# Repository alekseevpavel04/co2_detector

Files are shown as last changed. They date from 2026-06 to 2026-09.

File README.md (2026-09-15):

# co2_detector

A battery-powered indoor air-quality monitor built from off-the-shelf parts. It measures CO2, temperature and relative humidity, keeps a history on flash and draws the current CO2 level and graphs on an e-Paper screen. Hardware and firmware are assembled and working; screen design is still being refined (see [STATUS.md](STATUS.md)).

<p>
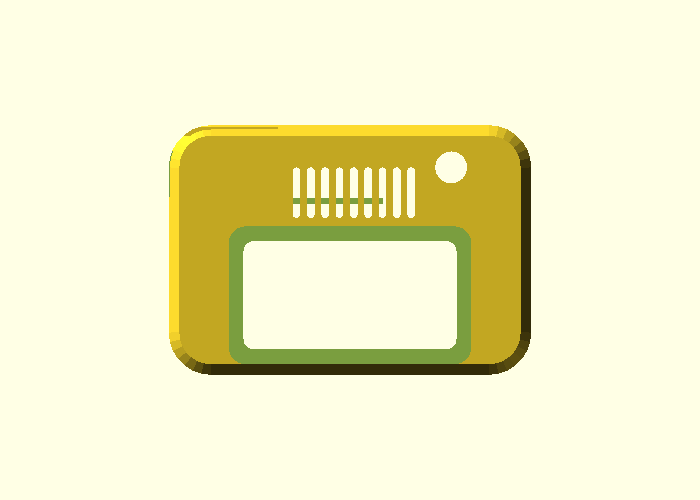
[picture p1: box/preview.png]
Case, front view
  
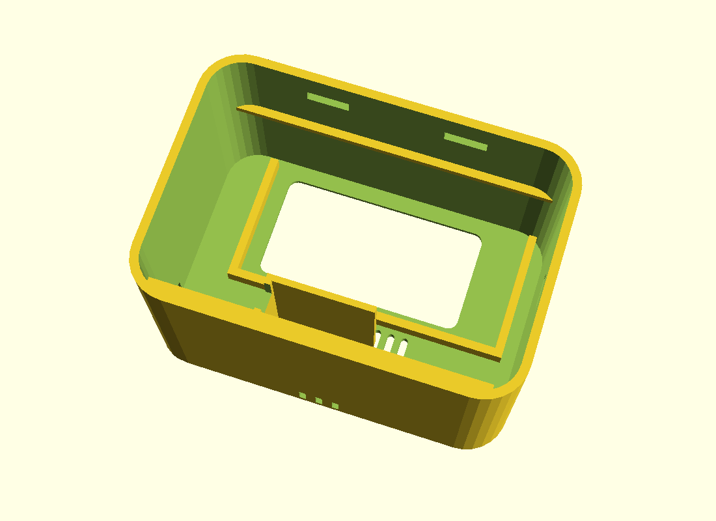
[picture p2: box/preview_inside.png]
Case with electronics inside
  
</p>

## Hardware

- **MCU:** ESP32-S3 SuperMini (4 MB flash)
- **Sensor:** Sensirion SCD41 (NDIR CO2, temperature, humidity) over I2C, single-shot measurements
- **Display:** Waveshare 2.13" e-Paper (250×122, GxEPD2 `BN` driver) over SPI
- **Input:** one button that cycles through the screens
- **Power:** 3×AA battery box with a switch, into the board's 5V pin

## Firmware

- PlatformIO + Arduino framework (`platformio.ini`, `src/main.cpp`).
- Deep sleep between measurements (every 15 minutes), light sleep while the SCD41 measures, CPU at 80 MHz during the active phase, the sensor powered down before sleep, e-Paper refreshed only when needed. The on-board LEDs were physically removed to cut idle current.
- Measurements stored in LittleFS as fixed-size binary records with file rotation; graphs for 1 h / 24 h / 7 days.
- Estimated battery life: about 8–10 months on alkaline AA and about a year on lithium AA. This is calculated from datasheets ([POWER.md](POWER.md)); it has not yet been confirmed by a full run on batteries.

## Tests

Hardware-independent logic lives in `lib/logic/` and is covered by Unity unit tests that run on the host, including an integration test on a synthetic month of data:

```bash
pio test -e native
```

Build and flash:

```bash
pio run -e esp32-s3-supermini -t upload
```

## Case

A 3D-printed FDM case modelled in OpenSCAD: [`box/case.scad`](box/case.scad) with the exported [`box/case.stl`](box/case.stl) (body, shelf and lid). Measured component dimensions are in [box/DIMENSIONS.md](box/DIMENSIONS.md).

## Repository layout

| Path | Contents |
|---|---|
| `src/` | Firmware (`main.cpp`, screen bitmaps) |
| `lib/logic/` | Pure logic: validation, downsampling, averages, navigation, alert hysteresis |
| `test/test_logic/` | Unity tests |
| `box/` | OpenSCAD case model, STL, renders |
| `Дизайн экрана/` | Screen design sources (PNG) |
| `Печать/` | Print-ready STL parts |

## Documentation (in Russian)

- [STATUS.md](STATUS.md): current state and remaining work
- [BRINGUP.md](BRINGUP.md): step-by-step assembly and hardware bring-up
- [POWER.md](POWER.md): power budget and battery-life estimate
- [BOX.md](BOX.md): case design and printing

## Кратко по-русски

Автономный монитор CO2, температуры и влажности на ESP32-S3 SuperMini, датчике SCD41 и e-Paper экране Waveshare 2.13", питание от 3×AA. Прошивка на PlatformIO/Arduino с глубоким сном и оптимизацией энергопотребления (расчётно 8–10 месяцев на щелочных батарейках), юнит-тесты логики на Unity, корпус для 3D-печати в OpenSCAD. Подробности в STATUS.md, BRINGUP.md, POWER.md и BOX.md.

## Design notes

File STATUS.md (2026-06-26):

# STATUS — где проект сейчас и что осталось

_Обновлено по итогам сборки и оптимизации. Подробности по энергии — в [POWER.md](POWER.md),
по сборке «с нуля» — в [BRINGUP.md](BRINGUP.md), полное ТЗ — в [CLAUDE.md](CLAUDE.md)._

## ✅ Готово — ЖЕЛЕЗО полностью собрано и работает

- **Состав:** ESP32-S3 SuperMini + SCD41 (CO2/T/RH) + e-Paper Waveshare 2.13" (драйвер **BN**) + **1 кнопка** (на GPIO5; вторая снята).
- **Питание:** бокс **3×AA с выключателем** → пин **5V**. (Опционально позже — LiPo на B+/B−, зарядка на плате есть.)
- **Все 3 паразитных светодиода удалены** (красный power, WS2812 RGB, синий charge) → низкое потребление.
- **Прибор работает автономно от батареек:** мерит CO2, рисует UI на e-Paper, спит 15 мин, кнопка листает 4 экрана.

## ✅ Готово — ПРОШИВКА (финальная на `main`, оптимизирована)

Все баги сборки пойманы и исправлены, энергопотребление вычищено. Ключевое:
flash 4 МБ, драйвер BN, надёжный замер SCD41, нет ложных пробуждений по кнопкам,
интервал 15 мин, light sleep на замере, ленивое обновление экрана, CPU 80 МГц.
(Список коммитов — в POWER.md.)

**Автономность (расчётная):** ~8–10 месяцев на щелочных AA, ~год на литиевых.

---

## 🔜 Осталось — ТОЛЬКО ПРОГРАММНОЕ

### 1. Оптимизация (по желанию — см. POWER.md «Остаточные рычаги»)
- Самое полезное и безопасное: **интервал 15 → 30 мин** (×~1.5 к автономности).
- Проверить по Serial и при необходимости убрать «кондиционирующий» двойной замер SCD41.
- Мелочи: CPU 40 МГц, partial refresh, внешние pull-up на кнопки.

### 2. Дизайн (UI на экране) — основная оставшаяся работа
- Доработка вёрстки/шрифтов/графиков на e-Paper (ориентир — раздел «Дизайн экрана» в CLAUDE.md).
- Сюда же — welcome-экран, расположение значений/светофоров, читаемость графиков.

### 3. TODO: навигация под ОДНУ кнопку (корпус теперь с одной кнопкой)
- Сейчас навигация на двух кнопках (`cycle_param` + `cycle_period`). Корпус под 1 кнопку.
- Переделать на одну: например короткое нажатие = следующий показатель, долгое =
  следующий период (или цикл по всем 9 экранам). Правка `src/main.cpp` + `lib/logic`.

### 4. Корпус (см. box/ — BOX.md, DIMENSIONS.md, case.scad/case.stl)
- Размеры компонентов замерены и вписаны. Перед заказом полной печати — пробник на
  принтере сервиса (защёлка крышки, посадки, реальный вылет дюпона).

## Железо трогать не нужно
Сборка и пайка завершены, прибор автономен. Дальнейшая работа — целиком в коде.

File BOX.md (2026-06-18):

# BOX.md — корпус под FDM-печать

Параметрическая модель — [`box/case.scad`](box/case.scad) (v6, стилевая переработка).
STL — [`box/case.stl`](box/case.stl): **3 отдельных объекта в одном файле** (корпус,
полка, крышка) — в слайсере «Split to objects», крутишь/печатаешь по отдельности.
Превью: [`box/preview.png`](box/preview.png) (лицо),
[`box/preview_inside.png`](box/preview_inside.png) (электроника + пины + дюпоны).

> **Дизайн (вариант B, стилевой):** корпус **сильно скруглён** (R8 по вертик. рёбрам).
> Лицо чистое и **симметричное**: экран **по центру** в **утопленной рамке со
> скруглёнными углами**, под ним по центру — **решётка датчика** (сенсор за ней дышит)
> + рельефная надпись «CO2». **Кнопка — на левом торце** (на лице ничего лишнего).
> ESP — справа-снизу, USB в правый торец. Выключатель (отдельный) — паз на правом
> торце у батарейного отсека. Крышка батарей: низ под губу + верх на 2 язычка.
> Размеры компонентов — замеренные (см. DIMENSIONS.md), запасы заложены.

> ⚠️ **Габарит ~87 × 55 × 50 мм — НЕ компактно, и виноваты разъёмы.** В модель добавлены
> реальные тела плат с пинами и **дюпон-мама**. Дюпоны торчат ~13 мм вертикально →
> отсек электроники ~20 мм глубиной → корпус глубокий. **Главный рычаг компактности:**
> угловые (right-angle) пины или пайка проводов напрямую вместо вертикального дюпона —
> тогда отсек ~8 мм, глубина падает до ~34 мм. См. `chamber_d` в `.scad`.

---

## Идея компоновки

Корпус-«кирпичик». Глубина разбита на **два уровня**, разделённых съёмной
полкой-перегородкой (всего **3 печатные детали**: корпус, полка, крышка):

```
            ЛИЦО (видит пользователь)
   ┌───────────────────────────────────────┐  ← лицевая стенка 2 мм
   │  ┌─────────────────────────────────┐  │     с окном под экран
   │  │   e-Paper 2.13" (активная зона) │  │
   │  └─────────────────────────────────┘  │
   │            ● btn1 (показатель)         │  ← 2 кнопки 12×12 СТОПКОЙ
   │            ● btn2 (период)             │     по центру, под экраном
   ├───────────────────────────────────────┤
   │  УРОВЕНЬ 2 — электроника (~8 мм):     │
   │  e-Paper · ESP32-S3 · SCD41 (в камере) │  ← закрыт полкой
   ├═══════════════════════════════════════┤  ← ПОЛКА-перегородка (съёмная)
   │  УРОВЕНЬ 1 — батарея (~20 мм):        │
   │  батарейный отсек 3×AA на полке        │
   └───────────────────────────────────────┘  ← крышка: низ под губу, верх на
            ТЫЛ                                   язычки-защёлки; доступ к батареям
```

- **Лицевая стенка**: окно под активную область экрана + 2 отверстия под кнопки.
- **Уровень 2 (электроника, ~8 мм)**: e-Paper сверху, ESP32 и SCD41 — в нижней
  полосе. Каждая плата держится **угловыми штырьками с защёлкивающим язычком**:
  вставил — язычки прижали к лицу (клей не нужен).
- **Камера SCD41**: датчик в правом нижнем углу отгорожен **перегородками** от общего
  объёма; вентиляция (правая + нижняя стенки) ведёт прямо в комнату. SCD41 — **один
  сенсор на CO₂ + температуру + влажность**, поэтому камера/вентиляция работают на все
  три показателя. Датчик дышит комнатным воздухом, а не тёплым внутренним.
- **Полка-перегородка** (отдельная деталь, лежит на полочках стенок + на камере SCD41):
  дно батарейного отсека и крышка электроники. На ней — **рёбра-держатели**,
  центрирующие отсек, **вырез под провода** батареи вниз к ESP, **палец-отверстие**
  чтобы вынуть полку. Открыл крышку → видна **только батарея**; электроника под полкой
  закрыта. Снять полку (для сборки/ремонта) — вынуть батареи и поддеть за отверстие.
- **Уровень 1 (батарея, ~20 мм)**: отсек 3×AA лежит на полке; тыльной гранью упирается
  в крышку (она его и держит).
- **Крышка** (как у батарейных отсеков): нижний край заходит **внахлёст под сплошную
  губу** (жёсткий зацеп, не гнётся → прощает допуск), верх держат **2 язычка-защёлки**
  за внутренние бусины (гнётся только эта пара). Заподлицо, без винтов и наружных
  дырок. Палец-выемка по центру верха — поддеть для снятия.
- **Боковой вырез под USB-C** напротив ESP32: разъём у этой платы на короткой грани,
  вырез в стенке прямо напротив → подключаешься **сбоку, не трогая ни крышку, ни
  полку**.
- **Кнопки** (тактовые **12×12 мм**, актуатор Ø7): две — **стопкой по вертикали** в
  центральной колонке между ESP и камерой датчика (там 24 мм — на одну 12-мм кнопку
  хватает с запасом по 6 мм). Гнездо 12×12 + **2 язычка**, которые прижимают корпус
  кнопки к лицу (без них нажатие просто продавит кнопку внутрь). Отверстие в лице
  Ø7.6 под актуатор; кнопка выступает наружу ~5 мм (нажимается напрямую, колпачок не
  нужен). Так габарит растёт минимально (+5 мм высоты, бОльшая сторона не меняется).
- **Разводка проводов**:
  - SCD41 ↔ ESP (I2C) и e-Paper ↔ ESP (SPI) — обе пары в одном уровне 2, провода идут
    в полости. Камера SCD41 имеет **вырез под кабель** (иначе датчик был бы заперт).
  - батарея ↔ ESP (питание) — через **вырез в полке** вниз к ESP.

Итоговый габарит ориентировочно **~74.8 × 63 × 34 мм** (уточнится после замеров).
Глубина 34 включает уровень полки. Высота 63 — нижняя полоса вмещает стопку из двух
кнопок 12×12 (и попутно SCD41 21 мм); бОльшая сторона (74.8) при этом не растёт.

---

## Вентиляция SCD41 — критично

SCD41 меряет CO₂ фотоакустически и **должен сообщаться с воздухом комнаты**. В
герметичном кармане показания CO₂ завышаются и запаздывают, а саморазогрев платы
завышает температуру. Поэтому:

1. **Отдельная камера**: датчик отгорожен перегородками от общего объёма корпуса —
   дышит комнатой, а не тёплым внутренним воздухом.
2. **Две щелевые вентиляции** прямо у сенсора (правая + нижняя стенки) → сквозной
   ток воздуха, а не застойный карман.
3. **Что вообще греется:** ESP32 почти не греется (99% времени deep sleep ~40 мкА,
   активен ~1–2 с раз в 15 мин). Главный локальный нагрев — **сам SCD41** при замере
   (фотоакустика + подогрев). Поэтому изолируем не ESP, а сам датчик (камера выше).
4. **SCD41 в дальнем от ESP углу** (ESP слева, датчик справа) — для подстраховки.
5. `TEMPERATURE_OFFSET` в прошивке (сейчас 2.0 °C) **перекалибровать после сборки в
   корпусе** — закрытый объём изменит саморазогрев.

---

## Доступы наружу

| Что | Где | Зачем |
|---|---|---|
| Окно экрана | лицо | видно показания |
| 2 кнопки | лицо, под экраном | листать показатель/период |
| USB-C | боковая стенка у ESP32 | прошивка/питание без вскрытия |
| Решётка SCD41 | правая + нижняя стенка (2 щели-группы) | сквозной воздухообмен |
| Выключатель батарей | в батарейном отсеке (виден при открытой крышке) | вкл/выкл |
| Крышка (тыл) | уровень 1 | замена батареек — видна только батарея |
| Полка-перегородка | под батареей | снять для доступа к электронике (сборка/ремонт) |

---

## Параметры модели (датшит → проверить калипером)

| Деталь | Размер (мм) | Источник | Проверить |
|---|---|---|---|
| ESP32-S3 SuperMini | 22.52 × 18 × ~6 | espboards.dev | толщину с USB-C, положение USB |
| e-Paper HAT (плата) | 65 × 30.2 × ~1.2 | Waveshare wiki | толщину стека со стеклом/FPC |
| e-Paper активная зона | 48.55 × 23.71 | Waveshare wiki | **смещение зоны от края платы** |
| SCD41 модуль | ~21 × 21 × ~8 | varies | **точные ШxДxВ своего модуля** |
| Батарейный отсек 3×AA | ~70 × 49 × 20 | Pi Hut/Kitronik | ШxДxВ + где выключатель/провода |
| Кнопки тактовые | 12 × 12, актуатор Ø7 | даташит | высоту корпуса за лицом (btn_can_h) |

**Самое важное замерить (от этого зависит, сядет ли):**
1. Батарейный отсек — все три габарита + положение выключателя и выхода проводов.
2. e-Paper: смещение активной зоны от края платы (для совмещения окна).
3. SCD41: точные габариты конкретного модуля + где отверстие сенсора.
4. ESP32: положение разъёма USB-C по краю (для бокового выреза).

---

## Печать

- **Материал:** PLA достаточно (прибор комнатный, не греется). PETG — если хочется
  прочнее/термостойче.
- **Ориентация:** лицевой стенкой **вниз** на стол — ровное окно, минимум поддержек.
- **Слой:** 0.2 мм. **Периметры:** 3. **Заполнение:** 15–20 %.
- **Поддержки:** при печати лицом вниз для основного корпуса не нужны; проверить
  нависания у выреза USB и решётки.
- **Зазор посадки** деталей `fit` в `.scad` = 0.4 мм (типично для FDM; подкрутить
  под свой принтер).

---

## Что дальше

1. **Согласовать конструкцию по рендерам** (`preview*.png`) — компоновка, гнёзда,
   сдвижная крышка, вентиляция. ← мы здесь.
2. **Купить калипер**, замерить 4 ключевых пункта выше, вписать в переменные `.scad`
   (или сказать мне — перегенерирую STL). От этого зависят зазоры гнёзд и пазов.
3. **Перед полным заказом** — напечатать дешёвый пробник (или фрагмент с гнездом и
   пазом крышки), проверить посадку плат и ход крышки на реальном принтере сервиса.
4. Тонкая подгонка под печать (итеративно):
   - зажимы плат: `post_clear` (боковой люфт) и `clamp_clear` (прижим без пережима);
   - крышка-низ: `lip_in` / `lip_zt` / `lip_clear` (нахлёст под губу);
   - крышка-верх: `tab_t` / `tab_arm` (жёсткость язычка), `barb_out` / `bead_in` (глубина
     зацепа). Язычкам, вероятно, понадобится фаска-заход — добавим на пробнике.
   - полка: `shelf_gap` (зазор над платами), `ledge_in` (опора), `wire_w` (вырез проводов).
   - кнопки: `btn_body` (12) / `btn_can_h` (высота корпуса за лицом) / `btn_act_d` (Ø7) под
     реальную кнопку; `lip`/`clamp_clear` — прижим язычков.

> ⚠️ Печать заказная — итерации дорогие. Гнёзда и пазы крышки **требуют точных
> размеров деталей**; без калипера плата либо не влезет, либо будет болтаться.

---

### Источники размеров
- ESP32-S3 SuperMini 22.52 × 18 мм — [espboards.dev](https://www.espboards.dev/esp32/esp32-s3-super-mini/)
- e-Paper 2.13" HAT: контур 65 × 30.2 мм, активная зона 48.55 × 23.71 мм — [Waveshare wiki](https://www.waveshare.com/wiki/2.13inch_e-Paper_HAT)
- SCD41 breakout ~20 × 20 мм (варьируется) — [Pimoroni](https://shop.pimoroni.com/en-us/products/scd41-co2-sensor-breakout), [Adafruit 25.4 × 17.8](https://www.adafruit.com/product/5190)
- Отсек 3×AA с крышкой/выключателем ~68–70 × 47.5–49 × 18–20 мм — [The Pi Hut](https://thepihut.com/products/battery-holder-3xaa-with-cover-and-switch), [Kitronik](https://kitronik.co.uk/products/2239-3xaa-battery-cage-with-leads-and-switch)
</content>
</invoke>

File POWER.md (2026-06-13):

# POWER.md — энергопотребление и автономность

Итоговое состояние и оценка. **Точного амперметра нет** (мультиметр HABOTEST HT123
ток не меряет; дешёвый USB-тестер слишком груб для нашего тока) — поэтому цифры
**расчётные** по даташитам. Финальное подтверждение — реальным прогоном на батарее.

## Железо (финал)
ESP32-S3 SuperMini (4 МБ) + SCD41 + e-Paper Waveshare 2.13" (драйвер **BN**) +
2 кнопки + бокс **3×AA с выключателем**. Питание: 3×AA (4.5 В) → пин **5V** → штатный LDO → 3.3 В.

**Убраны ВСЕ три паразитных светодиода:**
- 🔴 красный power-LED (горел всегда) — отломан;
- 🌈 WS2812 RGB (GPIO 48, ~0.6 мА даже погашенный — внутри активная микросхема) — отпаян;
- 🔵 синий charge-LED (мигал: вход есть, а LiPo на B+/B− нет → «no-battery blink») — отпаян.

Все три удаления проверены: плата стартует, экран/кнопки/датчик работают, **не греется** (короткого нет).

## Расчёт потребления

### Сон (~99% времени)
| Источник | Ток |
|---|---|
| ESP32-S3 deep sleep (домен RTC_PERIPH включён ради подтяжки кнопок) | ~25 мкА |
| Quiescent штатного LDO | ~10 мкА |
| e-Paper в hibernate | ~2 мкА |
| SCD41 в powerDown | ~0.15 мкА |
| Утечки платы | ~3 мкА |
| **Итого сон** | **~40 мкА → ~1 мА·ч/сут** |

### Актив (96 пробуждений/сут, раз в 15 мин)
| Фаза | За сутки |
|---|---|
| Замер SCD41 (5 с; ESP в light sleep ~1.5 мА, датчик ~15–18 мА) | ~2.5–5 мА·ч |
| ESP wake/init/read/sleep (80 МГц, ~1.2 с) | ~0.8 мА·ч |
| Обновление экрана (full refresh, когда меняется / раз в час) | ~1–2 мА·ч |
| Кнопки | ~0 |
| **Итого актив** | **~5–8 мА·ч/сут** |

### Итог: **~6–9 мА·ч/сут** (центр ~8), средний ток ~0.3–0.4 мА
Главный потребитель теперь — **сам замер CO2** (физика NDIR), а не паразиты. Это «полезный» ток.

## Прогноз автономности (3×AA)
| Батарейки | Полезно (до отсечки LDO ~3.6 В) | **Прогноз** |
|---|---|---|
| Щелочные AA | ~2200 мА·ч | **~8–10 месяцев** |
| Литиевые AA (Energizer Ultimate) | ~2900 мА·ч | **~год** |

## Что сделано (коммиты на `main`)
- `ff7f6ed` flash 4 МБ (иначе boot-loop).
- `fd1aa31` драйвер экрана GxEPD2_213_BN.
- `fd79820` надёжное пробуждение SCD41 (нет «No data через раз»).
- `b482fa0` RTC_PERIPH во сне → подтяжка кнопок жива (нет ложных пробуждений).
- `ca90631` интервал 15 мин + light sleep на замере + ленивый экран.
- `97d6a1e` CPU 80 МГц на активной фазе.
- (железо) удалены все 3 паразитных LED.

## Остаточные рычаги — ТОЛЬКО ПО, по желанию
| Рычаг | Эффект | Риск |
|---|---|---|
| 🟢 **Интервал 15 → 30 мин** | ×~1.4–1.5 (самый большой — замер теперь доминирует) | одна строка, 0 риска |
| 🟡 Убрать «кондиционирующий» 2-й замер, если он идёт каждый цикл | до −2.5 мА·ч/сут | сперва проверить по Serial |
| 🟡 CPU 80 → 40 МГц | ~0.5–1 мА·ч/сут | легко |
| ⚪ Header-only partial refresh | ~1 мА·ч/сут | рискованно (буфер кадра теряется в сне) |
| ⚪ Внешние pull-up 10к на GPIO4/5 → убрать RTC_PERIPH-on | ~0.5 мА·ч/сут | нужны 2 резистора |
| 🔋 Литий/D-элементы / LiPo на B+/B− | ×ёмкость (не расход) | покупка |

Дальше — диминишинг: всё крупное вычищено, упираемся в физику NDIR-замера.

## Решения
- **Зарядку (TP4056) отдельно НЕ делаем** — на плате уже есть (B+/B−); при желании v2 на LiPo (перезаряжаемый по USB).
- **Buck-boost (low-Iq) в обход LDO** — снял бы отсечку 3.6 В и поднял КПД, но это продвинутая доработка, пока не нужна.

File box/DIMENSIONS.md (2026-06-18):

# DIMENSIONS.md — замеры компонентов (источник истины для модели)

Все размеры в мм. Эти значения вписаны в переменные [`case.scad`](case.scad).
Замерено пользователем 2026-06-18 (калипер/даташиты/фото).

## Батарейный отсек 3×AA
- Габарит: **58 × 48 × 17**.
- Провода выходят **вниз** — не мешают.
- **Выключатель — отдельный, на проводе** (не на боксе). Под него паз **7 × 3 мм**
  в стенке батарейного отсека (доступ при открытой крышке).
- Переменные: `bat_l=58, bat_w=48, bat_h=17`, `sw_slot_w=7, sw_slot_h=3`.

## SCD41 (датчик CO2 / T / RH)
- Плата: **21.6 × 13.4 × 1.6**.
- Металлический сенсор (мембрана сверху): **8 × 8 × 6.5** (высота).
- Сенсор: по центру ширины платы, **~2 мм от дальнего (правого) края** по длине.
- Пины 1×4 (GND/VCC/SCL/SDA) — на **левом коротком крае**.
- Монтаж: сенсор уходит в круглое отверстие лица (мембрана дышит комнатой),
  плата опирается на сам сенсор, язычки прижимают.
- Переменные: `scd_l=21.6, scd_w=13.4, scd_t=1.6, can=8, can_h=6.5, scd_can_off=2`.

## e-Paper 2.13" (Waveshare)
- Контур платы: **65 × 30.2**.
- Активная (видимая) зона: **48.55 × 23.71**.
- Смещение активной зоны (замер): **слева 5, справа 10** (там FPC), **сверху/снизу 3.25**.
- **8-пиновый разъём — на самой плате экрана** (отдельной платы-драйвера НЕТ), провода/дюпон.
- Переменные: `epd_l=65, epd_w=30.2, act_w=48.55, act_h=23.71, act_ox=5, act_oy=3.25`.

## ESP32-S3 SuperMini
- Плата: **23.5 × 18**, толщина с компонентами ~6.
- USB-C — на коротком крае (по центру ширины), **3 мм толщиной, лежит на плате**
  (с платой 4.25). Вырез по высоте 3.5.
- Пины — на двух длинных краях.
- Переменные: `esp_l=23.5, esp_w=18, esp_h=6, usb_w=9.5, usb_h=3.5`.

## Кнопка тактовая 12×12
- Корпус: **12 × 12**, высота корпуса за лицом **3.3**.
- Актуатор: **Ø6.55**, торчит над корпусом **8.25**.
- Ноги ~3.5 за корпусом.
- Переменные: `btn=12, btn_can=3.3, act_d=6.55, act_out=8.25, btn_legs=3.5`.

## Разъёмы — дюпон-мама
- Сечение **2.5 × 2.5**, длина (торчит от платы) **до 17** (худший случай).
- Это главный потребитель глубины → `chamber_d=24`.
- Переменные: `dup_w=2.5, dup_h=17`.

---

## Итоговый габарит корпуса (из этих чисел)
**~87 × 55 × 50 мм.** Глубина — из-за вертикальных дюпонов (17 мм + загиб) + батарея (17).
Заложены щедрые запасы (см. блок «Запасы» в `case.scad`): платы `fit=0.5`, отсек
`chamber_d=27`, окно экрана +1 мм на сторону, вырез USB с запасом, гнездо кнопки +0.5.

## Статус замеров
Все ключевые размеры получены (e-Paper смещение, отсутствие платы-драйвера, USB —
закрыты). Остаётся проверить уже на печати/сборке:
- реальный вылет дюпона + загиб провода (если > ~20 мм — поднять `chamber_d`);
- посадки (зазоры) на пробной печати конкретного сервиса.

## Кнопка — ОДНА
Решено оставить **1 кнопку**. ⚠️ Это требует правки ПРОШИВКИ: сейчас навигация на
двух кнопках (cycle_param + cycle_period). Под одну кнопку — например: короткое
нажатие = следующий показатель, долгое = следующий период (или цикл по всем 9
экранам). Правка в `src/main.cpp` + `lib/logic`, отдельно от корпуса.
</content>

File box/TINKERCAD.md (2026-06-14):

# TINKERCAD.md — собираем корпус и учимся моделировать

> ⚠️ **Статус:** это гайд по **упрощённой v0** (простая коробка) — для обучения
> Tinkercad с нуля. Текущая рабочая конструкция (гнёзда-направляющие, сдвижная
> крышка, две вентиляции) живёт в [`case.scad`](case.scad) / [`case.stl`](case.stl)
> и её ведёт ассистент в OpenSCAD. Эти фичи руками в Tinkercad сложны — если хочешь
> их повторить, лучше печатать готовый STL. Гайд оставлен как учебный.

Пошаговая сборка корпуса в [Tinkercad](https://www.tinkercad.com) (браузер,
бесплатно, регистрация). Размеры — из [BOX.md](../BOX.md); эталон, к которому
стремимся — картинка [`preview.png`](preview.png).

> Это **v0 для обучения**: цель — собрать корпус и освоить инструмент. Крепления
> плат и фиксацию крышки доводим позже, когда будет калипер и точные размеры.

---

## Tinkercad за 5 минут — 6 понятий, и всё

1. **Фигуры** тянешь мышкой из панели справа на рабочую плоскость (Box, Cylinder…).
2. **Solid и Hole** — ГЛАВНАЯ идея. У любой фигуры справа вверху переключатель
   «Solid / Hole». **Hole** = «дырка»: сам по себе невидим, но когда ты
   **сгруппируешь** его с обычной фигурой — он вырежет из неё свою форму. Так
   делаются все отверстия и полости.
3. **Точный размер**: кликни фигуру → у неё появятся белые квадратики с числами →
   кликни число → впиши мм. (Проверь, что единицы — мм: *Edit grid* внизу справа.)
4. **Точное положение**: возьми инструмент **Ruler** (линейка, справа сверху),
   брось его на **передний-левый угол** внешней коробки. Теперь у каждой фигуры
   видно координаты X/Y/Z от этого угла — впиши нужные. (Стрелки на клавиатуре
   двигают на 1 мм.)
5. **Group (Ctrl+G) / Ungroup (Ctrl+Shift+G)** — объединить (применить дырки) и
   разъединить обратно. Группировка в Tinkercad **обратима**: сгруппировал —
   посмотрел результат, разгруппировал — поправил дырку. Не бойся группировать.
6. **Вид**: правая кнопка мыши вращает сцену, колесо — зум. Куб-навигатор в углу —
   повернуть к нужной грани (удобно заглянуть под низ).

Этого набора хватит на весь корпус.

---

## Ориентация

Моделируем корпус **лицом вверх** (как будто прибор лежит экраном к потолку):
- **верхняя грань** (Z сверху) = лицо с экраном и кнопками;
- **низ** = открытый тыл, туда потом встанет крышка;
- толщина лица и стенок — 2 мм.

(Как печатать — решит слайсер позже, ориентация в Tinkercad на это не влияет.)

---

## Размеры (просто впиши эти числа)

| Деталь | Размер X × Y × Z (мм) | Положение от угла-линейки (X, Y) |
|---|---|---|
| Внешняя коробка | 74.8 × 53.8 × 32 | 0, 0 |
| Полость (Hole) | 70.8 × 49.8 × 31 | 2, 2 (по центру), снизу |
| Окно экрана (Hole) | 48.55 × 23.71 × 5 | 12.9, 24.2 |
| Кнопка ×2 (Hole, цилиндр ⌀4) | ⌀4 × 5 | 29.4, 11.6 и 45.4, 11.6 |
| Вырез USB-C (Hole) | 6 × 9.5 × 4 | левая стенка (X≈−1), Y≈6.7 |
| Вент-слот (Hole) ×3 | 6 × 2 × 12 | правая стенка, над SCD41 |
| Крышка | 74.8 × 53.8 × 2 | отдельно |

---

## Шаг 1. Внешняя коробка
Перетащи **Box**. Задай размер **74.8 × 53.8 × 32**. Поставь **Ruler** на её
передний-левый угол → координаты станут 0, 0. Это наш «ноль».

## Шаг 2. Выдолбить полость
1. Перетащи ещё один **Box**, переключи его в **Hole**.
2. Размер **70.8 × 49.8 × 31**.
3. Поставь по центру: X=2, Y=2 (тогда стенки по 2 мм со всех сторон).
4. По высоте опусти его так, чтобы он **торчал из дна** и оставлял **верхние 2 мм**
   (лицо) целыми: подними Hole на Z так, чтобы его верх был на 30 (низ уйдёт ниже
   нуля — нормально, это вскрывает тыл).
5. Выдели обе фигуры → **Group**. Получилась «ванночка»: лицо сверху, 4 стенки,
   тыл открыт. Покрути вид снизу — убедись, что тыл открыт.

> Если что-то не так — **Ungroup**, поправь Hole, снова Group.

## Шаг 3. Окно экрана
1. **Box → Hole**, размер **48.55 × 23.71**, высоту **5** (чтобы наверняка
   проткнуть 2-мм лицо).
2. Положение X=**12.9**, Y=**24.2**. По Z поставь так, чтобы дырка прошла сквозь
   верхнюю грань (верх дырки выше 32, низ — внутри корпуса).
3. Пока **не группируй** — сложим все дырки и сгруппируем в конце (Шаг 7).

## Шаг 4. Отверстия под кнопки
**Cylinder → Hole**, диаметр **4**, высота **5**, две штуки:
- кнопка 1: X=**29.4**, Y=**11.6**;
- кнопка 2: X=**45.4**, Y=**11.6**.
Обе сквозь верхнюю грань (как окно).

> Совет: сделай одну, выдели, **Ctrl+D** (дубликат), сдвинь на 16 мм по X.

## Шаг 5. Вырез под USB-C (левая стенка)
ESP32 стоит под лицом в левом-нижнем углу, разъём смотрит в левую стенку.
1. **Box → Hole**, размер **6 (X) × 9.5 (Y) × 4 (Z)**.
2. Сдвинь к левой стенке: X≈**−1** (чтобы протыкал 2-мм стенку), Y≈**6.7**.
3. По Z — у самого лица: верх выреза примерно на **2–3 мм ниже** верхней грани.
   (Размер с запасом, точное место подгонишь после замера, где именно USB на плате.)

## Шаг 6. Вентиляция SCD41 (правая сторона) — слотами
Вместо сетки мелких дырок (их в Tinkercad муторно делать) режем **3 щели** —
проще и для воздуха работает так же.
1. **Box → Hole**, размер **6 (X) × 2 (Y) × 12 (Z)** — узкая высокая щель в правой
   стенке.
2. Прижми к правой стенке (X≈**73.8**, протыкает наружу), в зоне SCD41 (правый
   нижний угол, Y≈**5…20**).
3. Дублируй (**Ctrl+D**) ещё 2 раза, сдвигая по Y, чтобы получилось 3 щели рядом.
4. (Желательно) одну такую же щель — в **нижней стенке** под SCD41, для сквозняка.

## Шаг 7. Собрать всё
Выдели корпус и **все** Hole-фигуры (рамкой или Shift-клик) → **Group**. Все
отверстия вырежутся разом. Покрути, проверь окно/кнопки/USB/щели. Что не так —
Ungroup, правь, снова Group.

## Шаг 8. Крышка
Отдельная **Box** рядом: **74.8 × 53.8 × 2**. Пока просто пластина — как она
держится (защёлки/винты), решим в v1 после калипера.

## Шаг 9. Экспорт в STL
Выдели корпус → справа вверху **Export → .STL**. Отдельно экспортируй крышку.
Эти файлы потом откроешь в слайсере для печати.

---

## Когда купишь калипер
Замерь 4 пункта из [BOX.md](../BOX.md) («Самое важное замерить») и поправь числа в
Tinkercad — модель параметрами не связана, так что меняешь размеры руками у нужных
фигур. Самое критичное — **смещение окна экрана** (X=12.9, Y=24.2): зависит от
того, где активная зона на твоей плате.

## Если застрянешь
Опиши словами, что не получается (или скинь скрин) — подскажу шаг. А ещё у меня
остаётся OpenSCAD-эталон: могу отрендерить любой ракурс/срез, чтобы свериться.
</content>

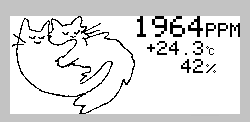
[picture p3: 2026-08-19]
Дизайн экрана/good.png

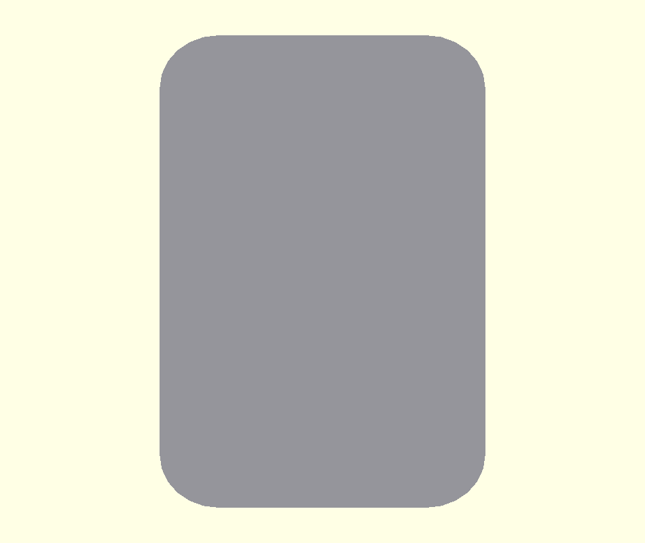
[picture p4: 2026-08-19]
box/_lid_bot.png

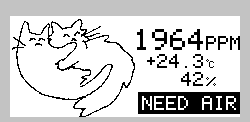
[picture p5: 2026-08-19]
Дизайн экрана/bad.png

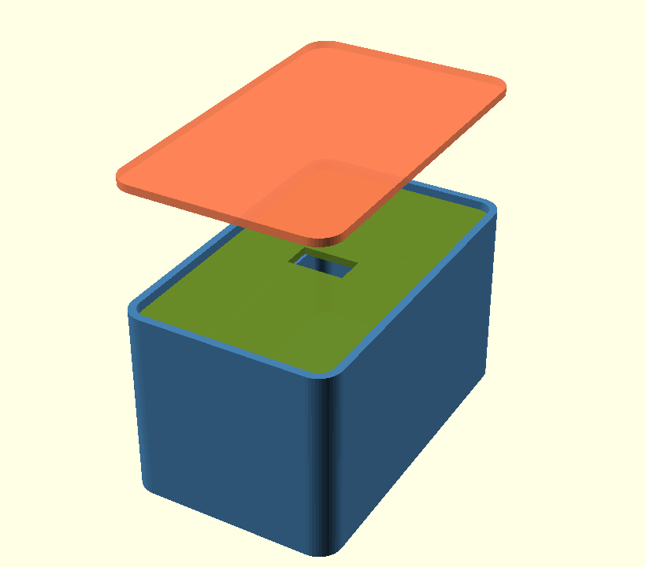
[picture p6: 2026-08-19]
box/_sh_iso.png

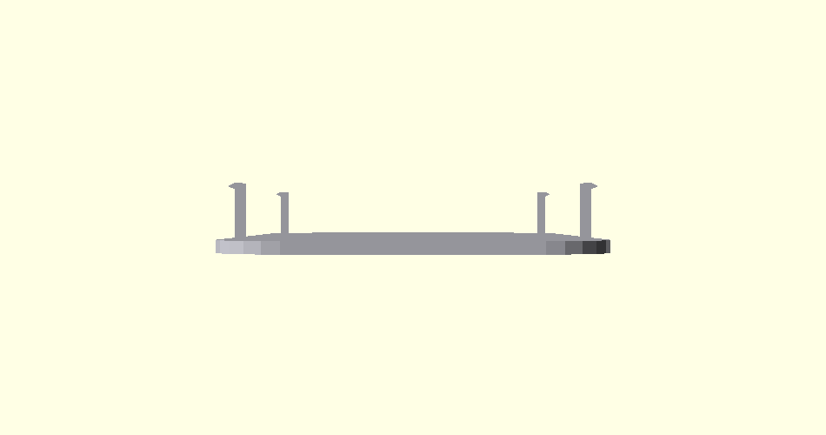
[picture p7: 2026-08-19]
box/_lid_edge.png

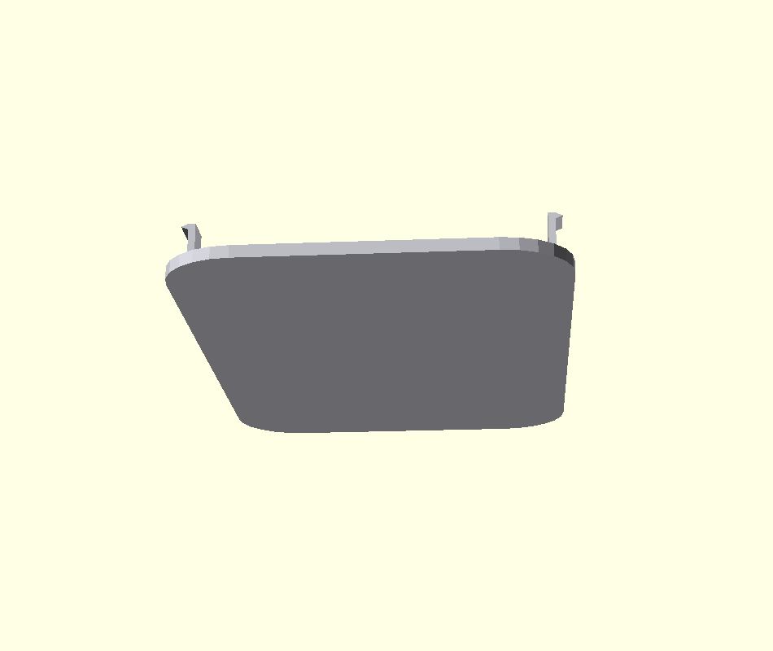
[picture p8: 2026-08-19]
box/_lid_iso.png

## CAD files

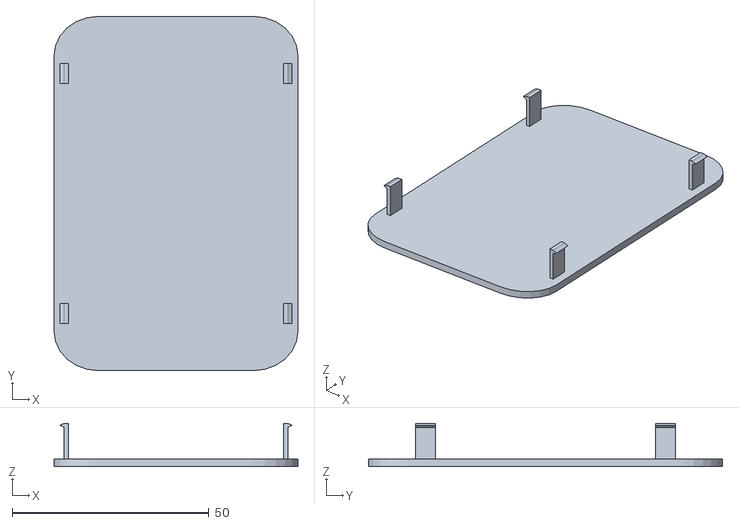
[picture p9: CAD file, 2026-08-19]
box/_lid.stl
62.0 x 90.0 x 11.0

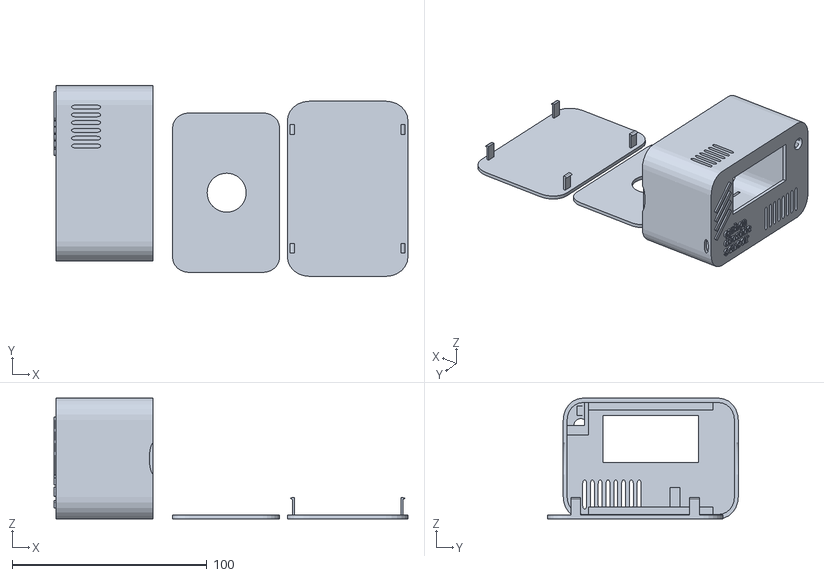
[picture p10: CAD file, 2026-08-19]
Печать/Все/print.stl
181.9 x 98.0 x 62.0

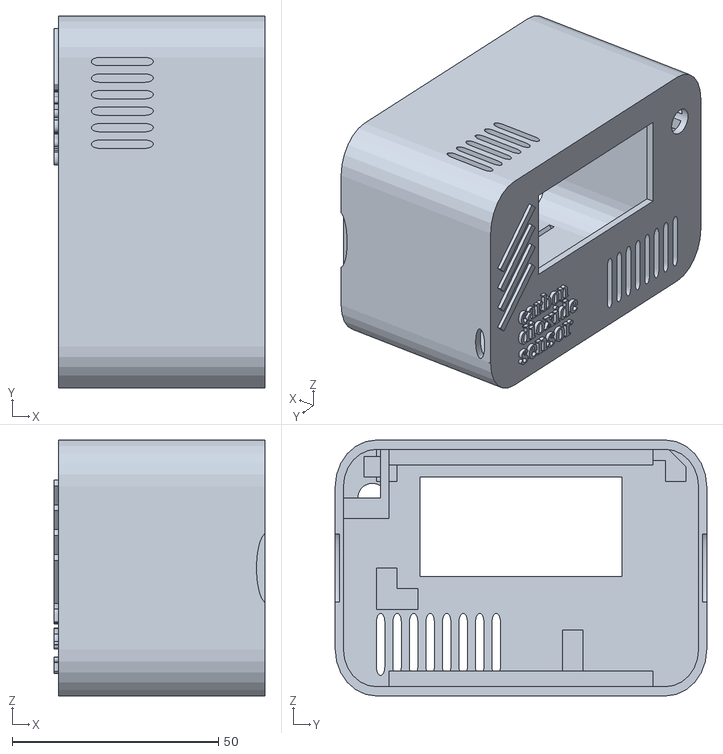
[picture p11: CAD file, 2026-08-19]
Печать/Деталь1/1.stl
51.0 x 90.0 x 62.0

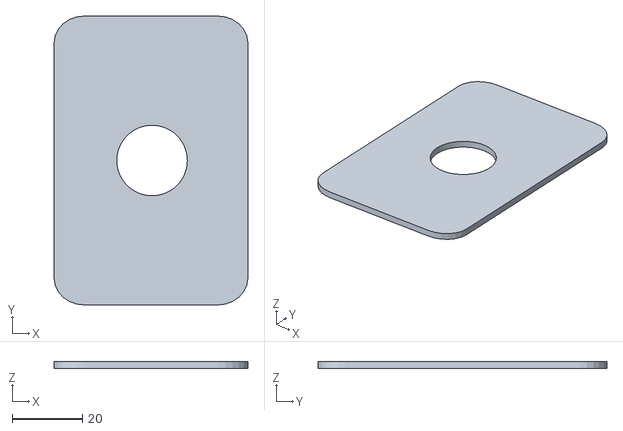
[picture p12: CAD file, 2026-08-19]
Печать/Деталь2/2.stl
55.0 x 82.0 x 2.00

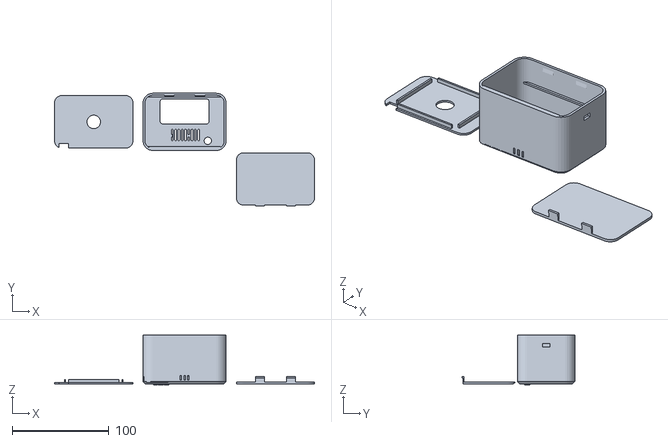
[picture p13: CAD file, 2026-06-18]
box/case.stl
269.0 x 116.4 x 51.3

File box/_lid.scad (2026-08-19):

part="iso";
P="C:/Users/PC/Desktop/co_detector/box/_lid.stl";
module m() color([0.75,0.75,0.78]) import(P,convexity=10);
cx=67; cy=-53; cz=5.5;
m();

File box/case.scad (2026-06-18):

// ============================================================
//  Air Quality Monitor — корпус (v7)
// ============================================================
//  Вариант B: чистое лицо — экран по центру (рамка), решётка датчика под ним,
//  кнопка справа, надпись «CO2» слева (симметрия). Корпус сильно скруглён (R10).
//  v7: убрана камера датчика (душила решётку) → датчик на 4 угловых опорах,
//  центр решётки и низ под шлейф экрана свободны. Крышка — СКРЫТАЯ защёлка:
//  низ под губой + верх за внутренними приливами (наружу нет дыр и язычков).
//  Размеры компонентов — замеренные (см. DIMENSIONS.md). Запасы заложены.
//  3 объекта в одном STL (корпус, полка, крышка). Ghosts с пинами+дюпоном.
// ============================================================

$fn = 32;

/* ---------- Стенки / допуски / стиль ---------- */
wall = 2.0; floor_t = 2.0; lid_t = 2.0;
fit  = 0.5;                 // зазор плата↔стенка
r_v  = 10;                  // скругление вертикальных рёбер (сильнее)
chamf = 2.5;                // фаска переднего ребра
r_win = 2.5;                // скругление углов окна экрана
bez_w = 4.5; bez_d = 1.3;   // утопленная рамка вокруг экрана (ширина, глубина)
win_margin = 1.0;           // окно крупнее активной зоны (допуск на смещение)

/* ---------- Запасы на посадки/вырезы ---------- */
btn_clear = 0.5; btn_hole_clr = 1.0;

/* ---------- e-Paper 2.13" ---------- */
epd_l = 65; epd_w = 30.2; epd_t = 1.2; epd_back = 4;
act_w = 48.55; act_h = 23.71;
act_ox = 5; act_oy = 3.25;   // смещение активной зоны от края платы

/* ---------- Кнопка тактовая 12×12 (на лице, справа-снизу) ---------- */
btn = 12; btn_can = 3.3; act_d = 6.55; act_out = 8.25; btn_legs = 3.5;

/* ---------- SCD41 (по центру под экраном, сенсор за решёткой) ---------- */
scd_l = 21.6; scd_w = 13.4; scd_t = 1.6;
can = 8; can_h = 6.5; scd_can_off = 2; scd_hdr_n = 4;

/* ---------- ESP32-S3 SuperMini (справа-снизу) ---------- */
esp_l = 23.5; esp_w = 18; esp_h = 6;
usb_w = 11; usb_h = 5.5;

/* ---------- Дюпон-мама ---------- */
hdr_h = 6; dup_h = 17; dup_w = 2.5;

/* ---------- Глубина отсека электроники (дюпоны 17 + запас) ---------- */
chamber_d = 27;

/* ---------- Батарея 3xAA + отдельный выключатель ---------- */
bat_l = 58; bat_w = 48; bat_h = 17;
sw_slot_w = 7.5; sw_slot_h = 3.5;        // паз под слайдер
// выключатель целиком (корпус+планка+пины) — для проверки места внутри, TODO:verify
sw_body_t = 7;   // вглубь от стенки (корпус+пины)
sw_body_l = 13;  // вдоль стенки (планка с ушками)
sw_body_h = 9;   // высота

/* ---------- Решётка вентиляции датчика ---------- */
grille_n = 9; grille_slot_w = 1.8; grille_pitch = 3.4; grille_slot_h = 12;   // больше/выше — вентиляция

/* ---------- Полка ---------- */
shelf_t = 1.5; shelf_gap = 1.0; ledge_in = 2.0; ledge_t = 1.5;
wire_w = 10; finger_d = 14; batt_rib = 1.5;

/* ---------- Крышка (скрытая защёлка: низ под губой + верх за приливами) ---------- */
lid_clear = 0.6;            // зазор-шов по периметру плиты = глубина зацепа защёлки
lip_in = 2.0; lip_zt = 1.0; lip_clear = 0.4;
tab_w = 9; tab_t = 1.2; tab_arm = 6; barb_h = 2.0; bead_len = 3.0;

label = "CO2";

// ============================================================
//  Производная компоновка
// ============================================================
inner_w = 82;                                   // шире — чтобы лицо вышло симметричным
inner_h = max(bat_w, epd_w + 6 + max(esp_w, scd_w)) + 2*fit;   // зазор экран↔низ
outer_w = inner_w + 2*wall;
outer_h = inner_h + 2*wall;

shelf_z = floor_t + chamber_d + shelf_gap;
bat_z   = shelf_z + shelf_t;
inner_d = (bat_z - floor_t) + bat_h;
lid_z0  = floor_t + inner_d;
outer_d = lid_z0 + lid_t;

// Окно (активная зона) — по центру X, в верхней части
win_x = (outer_w - act_w)/2;
win_y = wall + inner_h - act_h - 5;
epd_x = win_x - act_ox;
epd_y = win_y - act_oy;

// Решётка датчика — по центру X, ниже (явный зазор от экрана)
grille_cx = outer_w/2;
grille_cy = 10;
can_cx = grille_cx;
can_cy = grille_cy;
scd_x  = can_cx - (scd_l - scd_can_off - can/2);
scd_y  = can_cy - scd_w/2;

// ESP — низ-ЛЕВО, USB в ЛЕВЫЙ торец (освобождает право под кнопку)
esp_x = wall + fit;
esp_y = wall + fit;

// Кнопка — на ЛИЦЕ справа-снизу; надпись — слева-снизу (зеркально, для баланса)
btn_cx   = grille_cx + 24;
btn_cy   = grille_cy;
label_cx = grille_cx - 24;
label_cy = grille_cy;

// Батарея — по центру
bat_x = wall + (inner_w - bat_l)/2;
bat_y = wall + (inner_h - bat_w)/2;

// ============================================================
//  Помощники формы
// ============================================================
module rrect(w, h, r) {
    hull() for (x = [r, w-r]) for (y = [r, h-r]) translate([x, y]) circle(r = r, $fn = 28);
}
module rbody(w, h, d, r) {                      // призма со скруглёнными вертик. рёбрами
    linear_extrude(d) rrect(w, h, r);
}
module outer_body() {                           // корпус: скругление + фаска переднего ребра
    hull() {                                    // фаска у лица z=0..chamf
        linear_extrude(0.01) offset(-chamf) rrect(outer_w, outer_h, r_v);
        translate([0, 0, chamf]) linear_extrude(0.01) rrect(outer_w, outer_h, r_v);
    }
    translate([0, 0, chamf]) rbody(outer_w, outer_h, outer_d - chamf, r_v);
}

// ============================================================
//  Ghosts (тела + пины + дюпон)
// ============================================================
module header_dupont(x0, y0, z0, n) {
    pitch = 2.54;
    for (i = [0:n-1]) translate([x0 + i*pitch, y0, z0]) {
        color("silver") cylinder(d = 0.64, h = hdr_h);
        color("dimgray") translate([-pitch/2, -dup_w/2, 0]) cube([pitch, dup_w, dup_h]);
    }
}
module ghosts(show_bat = true, show_shelf = true) {
    color("green",0.5) translate([epd_x, epd_y, floor_t]) cube([epd_l, epd_w, epd_t]);
    color("dimgray",0.5) translate([epd_x+2, epd_y+2, floor_t+epd_t]) cube([epd_l-4, epd_w-4, epd_back]);
    color("white",0.7) translate([win_x, win_y, -0.1]) cube([act_w, act_h, floor_t+0.2]);
    header_dupont(epd_x+8, epd_y+1.5, floor_t+epd_t, 8);

    color("blue",0.5) translate([esp_x, esp_y, floor_t]) cube([esp_l, esp_w, esp_h]);
    header_dupont(esp_x+2, esp_y+1.5, floor_t+esp_h, 6);
    header_dupont(esp_x+2, esp_y+esp_w-1.5, floor_t+esp_h, 6);

    color("teal",0.5) translate([scd_x, scd_y, floor_t+can_h]) cube([scd_l, scd_w, scd_t]);
    color("silver") translate([can_cx-can/2, can_cy-can/2, floor_t]) cube([can, can, can_h]);
    header_dupont(scd_x+2, scd_y+scd_w/2-(scd_hdr_n*2.54)/2, floor_t+can_h+scd_t, scd_hdr_n);

    // кнопка на ЛИЦЕ: корпус за лицом, актуатор наружу (-Z)
    translate([btn_cx, btn_cy, 0]) {
        color("black",0.6) translate([-btn/2, -btn/2, floor_t]) cube([btn, btn, btn_can]);
        color("dimgray") translate([0,0,-act_out]) cylinder(d=act_d, h=act_out+floor_t+1);
    }

    if (show_shelf) color("gray",0.3) shelf();
    if (show_bat) {
        color("orange",0.18) translate([bat_x, bat_y, bat_z]) cube([bat_l, bat_w, bat_h]);
        // выключатель (слайдер с планкой) у правой стенки, в зоне батареи
        color("dimgray",0.6) translate([wall+inner_w-sw_body_t, wall+inner_h/2-sw_body_l/2, bat_z+bat_h/2-sw_body_h/2])
            cube([sw_body_t, sw_body_l, sw_body_h]);
    }
}
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

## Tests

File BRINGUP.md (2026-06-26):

# BRINGUP.md — от деталей на столе до работающего прибора

> **Для AI-ассистента (Claude):** этот файл рассчитан на пользователя
> БЕЗ опыта в электронике. При работе с ним:
> - Всегда сначала объясняй ЧТО это, потом КАК подключать.
> - Если пользователь говорит «не понимаю X» — объясни простыми словами,
>   не отсылай к Википедии.
> - Перед любым шагом, где режется/паяется/подключается питание — попроси
>   подтвердить визуально (фото / описание), если что-то неочевидно.
> - Цвета проводов в этом файле условные — у пользователя могут быть другие.
> - Идём строго сверху вниз. Не пропускаем разделы.

---

## Содержание

0. [Что конкретно у тебя на руках](#часть-0-что-конкретно-у-тебя-на-руках)
1. [Что должно лежать на столе](#часть-1-что-должно-лежать-на-столе)
2. [Что ещё нужно купить](#часть-2-что-ещё-нужно-купить)
3. [Базовые понятия за 5 минут](#часть-3-базовые-понятия-за-5-минут)
4. [Подготовка железа](#часть-4-подготовка-железа)
5. [Подготовка компьютера](#часть-5-подготовка-компьютера)
6. [Полная схема проводки](#часть-6-полная-схема-проводки-обзорная)
7. [Этапы прошивки и проверки](#часть-7-этапы-прошивки-и-проверки)
8. [Финал: корпус и батарейки](#часть-8-финал-корпус-и-батарейки)
9. [Параметры для подкрутки](#часть-9-параметры-для-подкрутки)
10. [Типичные проблемы](#часть-10-типичные-проблемы)

---

## Часть 0: Что конкретно у тебя на руках

Зафиксировано по фото, присланным пользователем. Эта секция — справочник по
конкретному комплекту; общие пояснения «что это вообще» — в Части 1 ниже.

### Чеклист комплекта

| Деталь | Что именно | Пайка |
|---|---|---|
| ESP32-S3 SuperMini | Плата + 2 планки штырьков **отдельно** (не впаяны) | **Да, 22 пина** |
| SCD41 | Модуль на синей PCB + 4-пиновая планка штырьков **отдельно** | **Да, 4 пина** |
| Waveshare 2.13" e-Paper HAT | Дисплей + плата-переходник + шлейф-кабель 8-pin (JST на одном конце, Dupont female на другом) **в комплекте** | Нет ✅ |
| Тактовые кнопки | **12×12×12 мм**, OFF-(ON), 10 шт | Да, по 2 провода к каждой (см. ниже) |
| Battery box | Бокс 3× AA, провода красный/чёрный с зачищенными концами | Нет |
| Breadboard | Стандартный full-size MB-102, ~830 точек, 4 шины питания | Нет (никогда) |
| Dupont провода 20 см | **120 шт**: 40 female-female + 40 male-male + 40 male-female | Нет |
| Инструменты | Паяльник, флюс, термоусадка, изолента | — |

### Дополнительно подтверждено пользователем

- **USB-C кабель «с данными»** — есть.
- **Мультиметр** — SakerX HT123 SMART (автоматический выбор диапазона, NCV,
  600 V CAT II) — есть/будет. Для наших задач (полярность 4.5 V перед
  батареями, прозвонка пайки) — с большим запасом.

### Итого по пайке у тебя

| Операция | Точек | Когда |
|---|---|---|
| Штырьки к ESP32-S3 | 22 | Часть 4.2 |
| Штырьки к SCD41 | 4 | Часть 4.3 (одновременно) |
| Провода к ножкам кнопок | 4 | Часть 4.3 (одновременно) |
| **Итого** | **~30 точек** | **~15-25 минут одной сессией** |

После этого паяльник убираешь и до самого финала (опциональная пайка для корпуса на Этапе 14) больше к нему не возвращаешься.

### Особенности именно ТВОИХ кнопок

Кнопки 12×12×12 мм — **больше**, чем стандартные 6×6 мм из обычных туториалов.
Их 4 ножки расположены в углах квадрата 12 мм, **шаг между ножками НЕ 2.54 мм**
(не вписывается в breadboard).

**Решение:** к каждой кнопке припаиваем **по 2 коротких провода** к двум
диагональным ножкам (диагональ — потому что у тактовой кнопки замыкаются именно
диагональные пары). Можно взять Dupont male-male проводок, разрезать пополам,
зачистить и припаять. Получаются «кнопки на хвостиках» — другой конец Dupont
втыкается в breadboard.

Сверху каждой пайки — кусочек термоусадки (у тебя есть), греется обычной
зажигалкой или паяльником на расстоянии — кусочек сжимается и защищает контакт
от замыкания на соседнюю ножку.

Подробности — в Части 4.3.

### Особенности именно ТВОЕГО e-Paper

У тебя HAT-версия Waveshare с уже установленным переходником. В комплекте идёт
**готовый кабель**: один конец — JST 8-pin (втыкается в плату HAT), другой —
8 индивидуальных Dupont female разъёмов с цветными проводами. **Никакой пайки
к экрану не нужно**, просто втыкаешь нужные провода в нужные GPIO на ESP.

Запомни/сфоткай порядок цветов в шлейфе после первой сборки — пригодится для
повторных подключений.

### Особенности именно ТВОЕГО battery box

Концы проводов уже **зачищены** (видна медь). Их можно либо:
- Воткнуть **напрямую в шины питания breadboard** (`+` и `−`) — для теста ОК.
- Припаять/обжать на Dupont male — надёжнее для постоянной работы.

Изоленту/термоусадку использовать на месте соединения, чтобы не было случайного
короткого замыкания.

---

## Часть 1: Что должно лежать на столе

### 1.1 ESP32-S3 SuperMini

**Что это:** «мозг» прибора. Маленькая (~22×18 мм) плата с микроконтроллером,
USB-C разъёмом и двумя рядами штырьков (или контактных площадок) по бокам.
Именно она будет выполнять прошивку, опрашивать датчик, рисовать на экране
и засыпать между измерениями.

**Как опознать:**
- Размер примерно с почтовую марку.
- На одном конце USB-C разъём.
- Где-то на плате микросхема с надписью `ESP32-S3` (под лупой видно).
- По бокам — по ~11 «дырочек» для штырьков (это и есть пины — выводы
  для проводов).

**Внимание:** существуют разные варианты этой платы от разных производителей.
Пины обычно подписаны прямо на плате — `GND`, `3V3`, `5V` (это питание),
а GPIO-пины — просто номерами `0`, `1`, `2`, ..., `48`. Если подписей
плохо видно — пригоди́тся лупа или фотография платы крупным планом.

**Вариант твоего комплекта:** ESP пришёл **без впаянных штырьков**, две планки
лежат отдельно — паять 22 пина (см. [Часть 0](#часть-0-что-конкретно-у-тебя-на-руках)
и подробности в Части 4.2).

### 1.2 Датчик SCD41

**Что это:** датчик CO2, температуры и влажности от Sensirion. Меряет
концентрацию углекислого газа методом фотонной спектроскопии (NDIR) —
светит инфракрасным светом и смотрит сколько поглощается, СO2 поглощает
определённую длину волны.

**Как опознать:** небольшая плата (~25×20 мм), на ней маленький
металлический «колпачок» (это сам сенсор Sensirion, выглядит как
квадратик ~10×10 мм). С одного края — 4 (или 6) штырька с подписями.

**Подписи на штырьках:**
- `VDD` или `VCC` или `+` — питание.
- `GND` или `−` — земля.
- `SDA` — линия данных I2C.
- `SCL` — линия тактов I2C.
- (Иногда: `INT`, `SEL`, `ADDR` — не используем, оставляем висеть.)

**Вариант твоего комплекта:** SCD41 пришёл **со штырьками отдельно** (4-пиновая
планка лежит рядом с модулем). Паять 4 пина — одновременно с пайкой ESP, см.
Часть 4.3.

### 1.3 Экран Waveshare 2.13" e-Paper

**Что это:** электронная бумага, похожая на дисплей читалки. Размер
картинки 250×122 пикселей, чёрно-белый. Главная фишка: после того как
картинка нарисована, экран **не нужно подпитывать** — изображение
сохраняется. Поэтому идеально для устройства на батарейках.

**Как опознать:**
- Прямоугольник ~30×60 мм, светло-серый/белый.
- С одной стороны от экрана выходит плоский гибкий шлейф (FFC/FPC)
  с тонкими медными дорожками.
- На конце шлейфа — небольшая плата-адаптер с 8 штырьками
  (для HAT-версии Waveshare). На штырьках подписи:
  `VCC`, `GND`, `DIN`, `CLK`, `CS`, `DC`, `RST`, `BUSY`.

**Если у тебя ДРУГОЙ форм-фактор (без платы-адаптера, только шлейф):**
понадобится переходник FPC-to-DIP. Скажи об этом Claude'у, он подскажет.

### 1.4 Две тактовые кнопки

**Что это:** обычные кнопки «вкл-на-время-нажатия». 4 ножки, но
функционально только 2 — **диагональные пары** соединяются при нажатии.
Параллельные ножки соединены всегда между собой (даже без нажатия).

**Как опознать:** маленький кубик с торчащими по углам ножками. При
нажатии слышен лёгкий «клик». Размер бывает разный — 6×6 мм или 12×12 мм,
функционально одно и то же.

**Вариант твоего комплекта:** у тебя **12×12×12 мм** (10 штук в упаковке,
маркировка `OFF-(ON)` — нормально-разомкнутая, замыкается только при нажатии).
Из-за размера ножки **не вписываются в стандартный шаг breadboard 2.54 мм** —
требуют пайки коротких проводов к 2 диагональным ножкам каждой кнопки.
Подробности — в [Части 0](#часть-0-что-конкретно-у-тебя-на-руках) и Части 4.3.

### 1.5 Бокс под 3 батарейки AA

**Что это:** пластиковая коробочка с пружинками внутри, в которую
вставляются 3 батарейки AA («пальчиковые»). Из бокса выходят два
провода: красный (+) и чёрный (−).

**Что туда вставлять:** **щелочные** (`alkaline`, например Duracell Basic)
или **литиевые** (Energizer Ultimate Lithium) батарейки AA.
**НЕ** аккумуляторы NiMH — у них напряжение 1.2 В, итого 3.6 В, чего
не хватит для устойчивой работы LDO на плате ESP.

### 1.6 USB-C кабель

**Что это:** обычный кабель USB-C. **Должен быть с данными**, а не
только для зарядки. Большинство кабелей от телефонов подходят, но
кабели для быстрой зарядки могут быть «питание-only» — тогда плата
просто не определится на компьютере. Если есть сомнения — проверим
на Этапе 1.

---

## Часть 2: Что ещё нужно купить

### Обязательно

#### Соединительные провода («Dupont jumper wires»)

Это разноцветные проводки с «папа»-штырьками или «мама»-гнёздами на
концах. Бывают трёх типов:

- **Female-Female (мама-мама):** оба конца — гнёзда. Подходит для
  соединения модулей друг с другом, если у обоих штырьки.
- **Male-Male (папа-папа):** оба конца — штырьки. Для breadboard.
- **Male-Female (папа-мама):** один конец штырёк, другой гнездо.

**Тебе нужны female-female** (около 20 штук, разных цветов). У наших
модулей (ESP, SCD41, e-Paper HAT) везде торчат штырьки, поэтому
нужны гнёзда.

#### Паяльник + припой ИЛИ предзапаянная плата

Плата ESP32-S3 SuperMini может приехать **без впаянных штырьков** —
тогда штырьки лежат отдельно, и их надо припаять. Это самая трудоёмкая
часть проекта.

**Варианты:**
- ✅ Заказать ESP уже с впаянными штырьками («with headers soldered»).
- ✅ Найти кого-то, кто запаяет (мастерская, друг-радиолюбитель).
- ✅ Купить дешёвый паяльник (300-500 руб), припой, флюс. Это навык на
  10 минут, в YouTube масса видео «как паять штырьки на ESP32».

Если штырьки уже впаяны — пайка не нужна вообще.

### Очень желательно

#### Breadboard (макетная плата)

Это пластиковая плата с дырочками, в которые вставляются штырьки. Внутри
дырочки соединены в группы — это позволяет соединять компоненты без пайки.

Маленькая (`half-size`, ~80×55 мм) — достаточно. Стоит копейки.

**Зачем нужно:** ESP вставляется штырьками в breadboard, и от других
рядов breadboard'а уже идут провода к датчику и экрану. Очень удобно
для прототипа.

**Можно без breadboard?** Можно, но придётся либо сделать паяные
соединения сразу (трудно поправить если ошибся), либо «висюли» из
проводов в гнёздах — ненадёжно.

#### Мультиметр

Прибор для измерения напряжения. Самый дешёвый (~500 руб) подойдёт.
Понадобится:
- Проверить напряжение батарейного бокса (Этап 14) — критично!
- Прозвонить проводку при отладке («есть ли контакт между точками А и Б»).

**Можно без мультиметра?** Можно, но при подключении батарей придётся
**особенно тщательно** проверить полярность визуально. Ошибка — сожжённый ESP.

### Опционально

- **Корпус** — пластиковый бокс на финальной стадии. Можно напечатать
  на 3D-принтере, можно купить готовый, можно собрать из картона
  и скотча на пробу.
- **Изоляционный материал** (например двухсторонний скотч) — приклеить
  компоненты к корпусу.

---

## Часть 3: Базовые понятия за 5 минут

### Питание

В электронике две «силовые» точки:
- **+** (плюс, VCC, VDD, 3V3, 5V) — откуда «вытекает» ток.
- **−** (минус, GND, «земля») — куда ток «втекает».

Цепь должна быть замкнутой: ток из + проходит через устройство и
возвращается в −. Если разомкнуть цепь — ничего не работает.

**Цифры (3.3 В, 5 В) — это напряжение.** Чем больше, тем сильнее «толкает»
ток. У нашей платы есть пин **5V** (вход для батареек) и пин **3V3**
(выход внутреннего регулятора, для питания датчика и экрана).

**Критично:** на пин `3V3` нельзя подавать больше 3.3 В! Это сожжёт чип.
Питание от батареек подаётся **ТОЛЬКО на пин 5V**, потому что внутри
ESP стоит регулятор (LDO), который превращает 4.5 В из батареек в 3.3 В.

### GND (земля)

GND — это общий «минус». На любой плате есть несколько пинов GND,
все они соединены друг с другом внутри платы. **Любые два модуля,
которые общаются друг с другом, должны иметь общий GND.**

### Что такое GPIO

GPIO = General Purpose Input/Output. Это «универсальный» пин, который
программно можно настроить либо как:
- **выход** (плата управляет: 0 В или 3.3 В на пин),
- **вход** (плата читает: 0 В или 3.3 В на пине от внешнего устройства).

GPIO пронумерованы (0, 1, ..., 48). В коде указываем номер GPIO, и плата
понимает что с ним делать.

### I2C — для общения с датчиком

**I2C** (произносится «ай-два-си» или «ай-ту-си») — простой протокол
общения по двум проводам:
- **SDA** (data) — данные.
- **SCL** (clock) — такт (отбивает «бит-бит-бит»).

Плюс общий GND. Итого 4 провода: VDD, GND, SDA, SCL.

**У SCD41 есть встроенные резисторы pull-up** на SDA и SCL (обычно).
Если бы их не было, провода «висели» бы в воздухе и сигналы плыли бы —
поэтому ставят резисторы, которые «подтягивают» линии к +. У современных
модулей это уже сделано на самом модуле, и ничего добавлять не надо.

### SPI — для общения с экраном

**SPI** — другой протокол, 4 провода:
- **MOSI** (Master Out Slave In, или просто DIN на экране) — данные от
  ESP к экрану.
- **MISO** — данные обратно. У нашего экрана не используется (он
  только принимает картинки, не отвечает).
- **SCK** или **CLK** — такт.
- **CS** (Chip Select) — «выбор устройства». Когда LOW — экран слушает.

Плюс ещё 2 управляющих пина:
- **DC** (Data/Command) — переключает между «это команда» и «это данные».
- **RST** (Reset) — сброс контроллера экрана.
- **BUSY** — экран сообщает: «я занят, не трогай меня».

### Кнопка

Простая кнопка просто соединяет два контакта при нажатии. У нас
подключение такое:
- Одна ножка кнопки → пин GPIO (4 или 5).
- Другая ножка → GND.

Когда кнопка не нажата — GPIO «висит». В коде включаем **pull-up**:
внутренний резистор подтягивает пин к +3.3 В. При нажатии — кнопка
коротит пин на GND, и плата видит «LOW». Так детектируется нажатие.

---

## Часть 4: Подготовка железа

### 4.1 Распаковка

Положи все детали перед собой. Сравни со списком в [Части 1](#часть-1-что-должно-лежать-на-столе).
Если чего-то нет — отметь, можешь начать без этой детали и докупить
по ходу (без датчика — до Этапа 2, без экрана — до Этапа 3, без кнопок —
до Этапа 6, без батареек — до Этапа 14).

### 4.2 Пайка штырьков в ESP (если ещё не запаяны)

**Если на твоей плате ESP уже торчат штырьки** — пропусти этот шаг.

Если в комплекте идут отдельные штырьковые планки — их нужно припаять
к плате. Это разовый шаг, после которого плата готова втыкаться в
breadboard или принимать гнёзда проводов.

**Базовый процесс:**
1. Вставь штырьки длинной частью в breadboard (так они выровняются).
2. Положи ESP сверху на короткие концы штырьков, дырочки совпадут.
3. Прогрей паяльником место «штырёк + контактная площадка ESP»,
   поднеси припой — он растечётся и схватится. ~2 секунды на пин.
4. По одному пину за раз. Не задерживайся надолго (плата может
   перегреться). 11 пинов с каждой стороны.

Если делаешь впервые — YouTube «как паять штырьки на ESP32». Это
проще чем кажется.

После пайки — проверь мультиметром на «прозвонку» (звуковой режим),
что соседние пины НЕ соединены друг с другом — иначе будет короткое
замыкание.

### 4.3 Подготовка остальных модулей и проводов

На этом шаге мы НЕ соединяем модули друг с другом — это будет в Части 6.
Сейчас **припаиваем оставшиеся штырьки/провода** и готовим Dupont-провода.

#### 4.3.1 Штырьки на SCD41 (4 пина)

Делается одной сессией вместе с пайкой ESP — паяльник уже горячий, флюс
открыт, навык свежий.

1. Воткни 4-пиновую планку штырьков в breadboard (длинной стороной вниз).
2. Положи модуль SCD41 сверху, дырочки совпадут с 4 штырьками.
3. Паяй с верхней стороны модуля, по одной точке за раз: касание ~1-2 сек,
   подаёшь припой к месту касания, он затекает в отверстие.
4. После 4 пайков — отпаяй от breadboard (просто снимай вверх).
5. Прозвонь мультиметром (если есть): между соседними штырьками НЕ должно
   быть короткого замыкания.

#### 4.3.2 Провода к кнопкам (если кнопки 12×12 мм)

Если у тебя кнопки **6×6 мм** — пропусти этот шаг, они влезают в breadboard
напрямую. Если **12×12 мм** (как в твоём комплекте) — делаем «кнопки на
хвостиках».

**Какие 2 ножки паять — диагональные.** У тактовой кнопки 4 ножки, но
функционально пар всего 2: ножки одной пары соединены **всегда** (даже без
нажатия), а при нажатии замыкаются между **диагональными** ножками.
Поэтому, чтобы кнопка работала как «нажал — замкнулось», провода
припаиваем к 2 **диагональным** (через угол) ножкам.

Шаги для каждой кнопки:

1. Возьми 2 провода Dupont male-male, разрежь каждый пополам — получишь
   4 половинки длиной ~10 см с одним концом «папа», другим зачищенным.
2. Зачисти 4 концов на 3-5 мм (если ещё не зачищены), скрути медные жилки.
3. Капни флюс на ножку кнопки и на конец провода.
4. Залуди (= покрой тонким слоем припоя) — приложи паяльник, подай припой,
   убери, ножка покрылась серебристым.
5. Сделай так же на конце провода.
6. Приложи зачищенный конец провода к ножке кнопки, прижми паяльником на
   1-2 сек — припой расплавится и слепится. Убери паяльник, держи провод
   пинцетом ещё ~3 сек до остывания.
7. Повтори для второй (диагональной!) ножки той же кнопки.
8. Надень кусочек термоусадки ~5 мм на каждую пайку, прогрей паяльником
   на расстоянии (не касаясь) или зажигалкой — термоусадка сожмётся и
   защитит контакт.
9. Повтори всю процедуру для второй кнопки.

Результат: 2 кнопки, у каждой по 2 провода с male-разъёмами Dupont на
свободных концах. Эти male-разъёмы будут втыкаться в breadboard.

#### 4.3.3 Dupont-провода для остальных соединений

Просто отбери из своей пачки нужные количества:
- **4 провода female-female** для SCD41 (VDD, GND, SDA, SCL) — модуль SCD41 теперь со штырьками, breadboard в другой стороне.
- **0 проводов для e-Paper** — у тебя уже есть готовый шлейф-кабель в комплекте с HAT (JST↔Dupont female), его и используем.
- **Кнопки** — уже подготовлены в 4.3.2.

Длина 20 см — норм, можно и подлиннее если будешь делать стационарный стенд.

**Цвет — для собственного удобства:**
- Красный — для питания (+, VCC, VDD, 3V3, 5V).
- Чёрный — для земли (GND, −).
- Любые другие цвета — для данных.

Не критично использовать именно эти цвета, но **сильно поможет** при
проверке проводки: красный → красный, чёрный → чёрный сразу видно.

---

## Часть 5: Подготовка компьютера

### 5.1 Установка PlatformIO

PlatformIO — это среда для прошивки ESP. Два варианта:

**Вариант A (рекомендуется): VS Code + PlatformIO extension**
1. Скачай VS Code: https://code.visualstudio.com
2. Установи.
3. Открой VS Code, в боковой панели слева — иконка «Extensions»
   (квадратики). Найди «PlatformIO IDE», установи. Подожди несколько
   минут — оно докачает.

**Вариант B: PlatformIO CLI**
Если уже стоит Python 3.8+:
```bash
pip install platformio
```
И всё. Команды `pio` и `platformio` теперь работают в терминале.

В этом проекте у нас уже стоит CLI (Этап работы с Claude был через CLI).

### 5.2 Клонирование репозитория

Открой терминал, перейди в папку для проектов (например `Desktop`):
```bash
cd Desktop
git clone git@github.com:alekseevpavel04/co2_detector.git
cd co2_detector
```

Или если ты сейчас находишься в репозитории — пропусти этот шаг.

### 5.3 Подключение ESP к компьютеру по USB

1. Воткни ESP в USB-C **отдельный**, без других подключений.
2. Если есть встроенный RGB-светодиод — он может мигнуть синим/белым
   (это нормально, плата запускается с заводской прошивкой или с тем
   что было).
3. Открой терминал в папке `co2_detector`, набери:
   ```bash
   pio device list
   ```
4. Должна появиться строчка типа:
   ```
   COM5  (или /dev/ttyUSB0, /dev/cu.usbmodem...)
   ...
   USB VID:PID=303A:1001 ...
   ```
   `303A` — это Espressif. Значит плата опозналась.

**Если плата НЕ опозналась:**
- Кабель charge-only. Поменяй.
- Драйверы (Windows иногда требует CH340 или CP2102 — но ESP32-S3 обычно
  работает на встроенном USB, драйверы не нужны).
- BOOT+RESET процедура: зажми BOOT, кратко нажми RESET, отпусти BOOT.
  Снова `pio device list`.

---

## Часть 6: Полная схема проводки (обзорная)

Это **итоговая** картина — куда что подключено в финале. Сейчас её
читать целиком, потом во время прошивки этапов мы будем подключать
части постепенно.

### 6.1 Таблица соединений

| ESP32-S3 пин | Куда | Назначение |
|---|---|---|
| `3V3` | SCD41 `VDD` **и** e-Paper `VCC` | питание датчика и экрана |
| `GND` | SCD41 `GND`, e-Paper `GND`, обе кнопки (одна ножка), батарейный бокс `−` | общая земля |
| `5V` | батарейный бокс `+` (только на финальной сборке!) | питание от батарей |
| `GPIO 4` | кнопка 1, вторая ножка | кнопка «показатель» |
| `GPIO 5` | кнопка 2, вторая ножка | кнопка «период» |
| `GPIO 6` | e-Paper `RST` | сброс экрана |
| `GPIO 7` | e-Paper `BUSY` | «экран занят» |
| `GPIO 8` | SCD41 `SDA` | I2C данные |
| `GPIO 9` | SCD41 `SCL` | I2C такт |
| `GPIO 10` | e-Paper `CS` | выбор экрана |
| `GPIO 11` | e-Paper `DIN` (MOSI) | SPI данные |
| `GPIO 12` | e-Paper `CLK` (SCK) | SPI такт |
| `GPIO 13` | e-Paper `DC` | команды/данные |

### 6.2 ASCII-схема (обзор)

```
              ┌──────────────────────┐
              │   ESP32-S3 SuperMini │
              │                      │
              │ USB-C ━━━━━━━━━━ для прошивки
              │                      │
              │   3V3 ───┬──────────────────┬────── e-Paper VCC
              │          │                  │
              │   GND ───┴──┬────────────┬──┴────── e-Paper GND
              │             │            │
              │   5V        │            │       (только финал, к батарейкам)
              │             │            │
              │   GPIO 4 ───┼──[ кнопка 1 ]─── GND
              │   GPIO 5 ───┼──[ кнопка 2 ]─── GND
              │             │
              │             └──> SCD41 VDD (3V3 общая шина)
              │                  SCD41 GND
              │   GPIO 8 ─────── SCD41 SDA
              │   GPIO 9 ─────── SCD41 SCL
              │
              │   GPIO 6 ─────── e-Paper RST
              │   GPIO 7 ─────── e-Paper BUSY
              │   GPIO 10 ────── e-Paper CS
              │   GPIO 11 ────── e-Paper DIN  (MOSI)
              │   GPIO 12 ────── e-Paper CLK  (SCK)
              │   GPIO 13 ────── e-Paper DC
              └──────────────────────┘
```

### 6.3 Главные правила безопасности

1. **Никогда не подключать батарейный бокс на пин 3V3.** Только на 5V.
2. **Перед подключением батарей** проверить полярность мультиметром:
   красный провод даёт `+4.5 В` относительно чёрного. **Перепутанная
   полярность сожжёт ESP.**
3. **Не использовать одновременно** USB + батарейки. На время прошивки
   и отладки — только USB. Когда переключаемся на батарейки — USB
   физически вынуть.
4. **Перед изменением проводки** — отключить USB.
5. **Не закорачивать** + и − случайным проводом (например упавшим
   на стол).

---

## Часть 7: Этапы прошивки и проверки

> С этого момента — каждый этап это один коммит в git. Идём по очереди.
> Для каждого этапа: подключи нужные модули → собери и прошей → открой
> Serial Monitor → сравни с «ожидаемым выводом» → если ок, перейди к
> следующему.

### Общие команды (запоминать не надо)

```bash
# Перейти на нужный коммит (этап)
git checkout <commit_hash>

# Стереть всю флешку (один раз перед самой первой прошивкой)
pio run -e esp32-s3-supermini -t erase

# Собрать + прошить + открыть мониторинг Serial
pio run -e esp32-s3-supermini -t upload -t monitor

# Просто открыть мониторинг (если уже прошито)
pio device monitor

# Выйти из мониторинга: Ctrl + C
```

**Если upload не входит в bootloader** (ошибка «Failed to connect»):
зажми BOOT → кратко нажми RESET → отпусти BOOT → запусти upload снова.

---
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

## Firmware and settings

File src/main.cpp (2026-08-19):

#include <Arduino.h>
#include <Wire.h>
#include <SPI.h>
#include <LittleFS.h>
#include <esp_sleep.h>
#include <driver/rtc_io.h>
#include <SensirionI2cScd4x.h>
#include <SensirionErrors.h>
#include <GxEPD2_BW.h>
#include <Fonts/FreeSans9pt7b.h>
#include <Fonts/FreeSans12pt7b.h>
#include <Fonts/FreeSansBold9pt7b.h>
#include <Fonts/FreeSansBold12pt7b.h>
#include <Fonts/FreeSansBold24pt7b.h>
#include <Fonts/Picopixel.h>
#include "main_screen.h"
#include "graph24_shell.h"
#include "graph7d_shell.h"

#include <vector>
#include <algorithm>
#include <cstring>

#include "logic.h"

// ============================================================
// Этап 14: Polish + batterу
// ============================================================
// Что доделали:
//   - VERBOSE_LOGGING управляет шумом в Serial: при 0 остаются
//     только важные сообщения (ошибки, состояния алерта, размеры
//     файлов). Для отладки можно временно поднять.
//   - Убрали технический долг — дубликат TARGET_POINTS_FWD удалён,
//     forward-declaration оставлена только для функции
//     load_recent_measurements.
//
// Дополнительно к финальному запуску:
//   - Подключить батарейный бокс (3× AA → 5V, не 3V3!),
//     отключить USB и замерить автономность (см. ТЗ).
//   - Интеграционный тест (test/test_logic/test_integration.cpp)
//     эмулирует месяц данных и прогоняет валидация → averages →
//     downsampling, проверяя что вся pipeline не падает.
// Что нового:
//   - Две кнопки на GPIO 4 («показатель») и GPIO 5 («период»).
//     Один контакт каждой — на GND, второй — на GPIO. Внутренний
//     pull-up через rtc_gpio_pullup_en (КРИТИЧЕСКОЕ #7).
//   - Источников пробуждения теперь два:
//       TIMER → стандартный цикл: измерение → отрисовка → sleep.
//       EXT1  → нажата кнопка: меняем current_screen, перерисовываем
//               текущий экран (датчик не трогаем), sleep.
//   - current_screen в RTC memory переживает sleep.
//   - last_co2/temp/humidity тоже в RTC — чтобы при пробуждении
//     по кнопке было что отрисовать (без нового измерения).
//   - Перед каждым go_to_sleep() ждём отпускания кнопок,
//     иначе ESP-IDF проснётся снова на той же кнопке (бесконечный цикл).
//
// Отрисовка пока заглушка: «Screen N: <param> for <period>» + последние
// значения. Реальные графики появятся с Этапа 9.

// --- Пины ---
#define PIN_SDA            8
#define PIN_SCL            9
// В корпусе осталась ОДНА кнопка — на GPIO 5. Она листает экраны по кругу.
// GPIO 4 (бывшая вторая кнопка) физически не подключён — не используем.
#define PIN_BUTTON_PARAM   4    // RTC GPIO 4 — не используется (кнопка снята)
#define PIN_BUTTON_PERIOD  5    // RTC GPIO 5 — единственная кнопка (листание)
#define PIN_BUTTON         PIN_BUTTON_PERIOD
#define PIN_EPD_CS         10
#define PIN_EPD_MOSI       11
#define PIN_EPD_SCK        12
#define PIN_EPD_DC         13
#define PIN_EPD_RST        6
#define PIN_EPD_BUSY       7
#define LED_PIN            48
#define LED_LEVEL          32

// --- Интервалы ---
#define MEASUREMENT_DELAY_MS    5000
#define MEASUREMENT_INTERVAL    900        // sleep между замерами, сек (15 мин — экономия батареи)

// --- Калибровка температуры (SCD41) ---
// ВАЖНО: датчик хранит "temperature offset", который ВЫЧИТАЕТСЯ из показания,
// чтобы скомпенсировать саморазогрев. Заводское значение = 4.0 °C и рассчитано
// на НЕПРЕРЫВНЫЙ режим, где чип греется ~на 4°. Мы же меряем в single-shot:
// датчик почти всё время выключен и не греется → вычитать 4° нельзя, иначе
// температура стабильно занижена на ~4° (и «гуляет» из-за разогрева во время
// самого замера). Поэтому для single-shot ставим офсет близкий к нулю.
// setTemperatureOffset() пишет только в RAM датчика (без износа EEPROM), а при
// powerDown настройка сбрасывается — поэтому задаём её КАЖДЫЙ цикл перед замером.
// После сборки сравни показание с отдельным термометром и подкрути это число
// (если прибор показывает на X° меньше реального — УМЕНЬШИ офсет на X).
// ПРОВЕРЕНО 2026: 10 парных замеров с Xiaomi — расхождение в среднем +0.1 °C
// (максимум 0.6), т.е. температура калибровки не требует, офсет остаётся 0.
#define TEMPERATURE_OFFSET      0.0f

// Калибровка влажности. У SCD41 НЕТ аппаратного регистра офсета для RH (только
// для температуры), поэтому правим программно: это число (в % RH) прибавляется
// к показанию датчика — и на экране, и в файле, чтобы история была единообразной.
// Подкрутка: прибор показывает на X% МЕНЬШЕ реального → УВЕЛИЧЬ офсет на X.
//
// ЗАМЕР 2026: 10 парных сравнений (36–54 %RH, 22.9–26.8 °C) с гигрометром
// Xiaomi (SHT3x-класс, паспорт ±3 %RH) и с ноунейм-китайцем:
//   Xiaomi − наш: 10,11,10,9,10,10,10,8,9,8  → среднее +9.5, медиана +10
//   ноунейм − наш: 1,2,1,0,3,1,0,0,0,0       → среднее +0.8 (совпадает с нашим)
// Линейная регрессия наш→Xiaomi даёт y = 0.87·x + 14.9, т.е. почти чистый
// сдвиг: константа +9.5 держит ошибку в пределах ±1.5 %RH во всём диапазоне,
// поэтому усложнять (gain+offset) смысла нет.
// Почему верим Xiaomi, а не «двум против одного»: (1) у SCD41 RH — вторичный
// канал с паспортной точностью ±6 %RH, у Xiaomi ±3 %; (2) ноунейм при этом
// завышает температуру на +0.5 °C, т.е. сам плохо откалиброван; (3) физика:
// 37 % при 25 °C в июле — это влажность отопительного сезона, для лета
// нереально сухо, а 47–50 % (и 62 % в конце августа) — норма.
// САМОРАЗОГРЕВА в занижении не винить: температура нашего датчика совпадает
// с Xiaomi (+0.1 °C в среднем), т.е. кристалл не горячее воздуха.
#define HUMIDITY_OFFSET         9.5f

// --- Режим НАСТРОЙКИ (для итеративной доводки UI по USB) ---
// 1 = плата НЕ уходит в сон вообще, CPU держим на 240 МГц → USB-CDC порт
//     стабильно поднят и не пропадает. Это позволяет перепрошивать прибор
//     сколько угодно раз без «ловли» окна пробуждения. На экране — "TUNING
//     MODE" + живые значения.
//     ТЕПЕРЬ режим переключается НА ЛЕТУ: удерживай кнопку ~10 c — прибор
//     уйдёт в SETUP (без сна, USB живой); удержишь ещё раз — вернётся в
//     нормальный. Флаг живёт в RTC-памяти (переживает deep sleep, сбрасывается
//     при полном обесточивании). Значение ниже — лишь ДЕФОЛТ при первой
//     загрузке / после снятия батарей (0 = нормальный режим).
#define TUNING_MODE             0
#define LONG_PRESS_MS           10000      // мс — удержание для смены режима (~10 c)
#define AVERAGE_RECALC_INTERVAL 86400      // пересчёт средних раз в сутки
#define BUTTON_RELEASE_TIMEOUT  3000       // мс — сколько ждём отпускания

// --- Тестовая синтетика для проверки графиков ---
// 1 = при старте (если ещё не засеяно) затереть /data и записать 7 суток
// синтетических данных (часовой цикл + многосуточный тренд). Меняешь паттерн —
// подними SEED_VERSION, чтобы пересеять. ПЕРЕД боевым использованием → 0.
#define SEED_SYNTHETIC          0
#define SEED_VERSION            3

// --- Экономия экрана (e-Paper держит картинку даром; full refresh дорогой) ---
// По таймеру перерисовываем только если значение заметно изменилось, либо
// прошёл FULL_REFRESH_INTERVAL (от «теней»), либо сменился алерт.
#define FULL_REFRESH_INTERVAL   3600       // сек — не реже раза в час полный refresh
#define REDRAW_CO2_DELTA        30         // ppm
#define REDRAW_TEMP_DELTA_X10   3          // 0.3 °C (в десятых)
#define REDRAW_HUM_DELTA        2          // %

// --- Драйвер e-Paper ---
// На нашей панели Waveshare 2.13" работает именно BN (SSD1680).
// С B73 контроллер отрабатывает обновление, но стекло остаётся пустым.
#define EPD_DRIVER     GxEPD2_213_BN

#define RTC_MAGIC      0xDEADBEF1   // bump при изменении набора RTC-переменных (форсит чистый init)
// Новый UI: 4 экрана, всё про CO2.
//   0 — MAIN (крупное текущее значение + статус)
//   1 — график CO2 за 1 час
//   2 — график CO2 за 24 часа
//   3 — график CO2 за 7 дней
// Одна кнопка (GPIO5) листает экраны по кругу. По таймеру всегда
// возвращаемся на MAIN. Экраны: 0=MAIN, 1=график 24ч, 2=график 7д.
// (График за 1ч убран — при 15-мин интервале там всего 4 точки.)
#define N_SCREENS      3
#define SCREEN_MAIN    0

// --- Хранилище ---
#define MAX_FILE_SIZE  (90 * 1024)   // байт. 9000 measurement ≈ 31 день при 5-мин интервале.
#define MAX_FILES      13            // суммарно 90 КБ × 13 ≈ ~400 дней истории.

// --- Шкалы графиков ---
#define CO2_SCALE_MIN     400
#define CO2_SCALE_MAX     2000
#define TEMP_SCALE_MIN    15
#define TEMP_SCALE_MAX    30
#define HUMIDITY_SCALE_MIN 20
#define HUMIDITY_SCALE_MAX 80

// --- Идеальные значения (для линии трендов) ---
#define IDEAL_CO2         600
#define IDEAL_TEMP        22.0f
#define IDEAL_HUMIDITY    50

// --- Пороги «плохо» (для пунктирной линии на графике) ---
#define CO2_THRESHOLD_HI       1500
#define TEMP_THRESHOLD_LO      18.0f
#define TEMP_THRESHOLD_HI      26.0f
#define HUMIDITY_THRESHOLD_LO  30
#define HUMIDITY_THRESHOLD_HI  70

// --- Управление визуализацией трендов ---
#define SHOW_IDEAL_LINE      1
#define SHOW_AVERAGE_LINE    1
#define SHOW_THRESHOLD_BAD   1

// --- Отладка ---
// 1 — подробный лог в Serial (запись измерений, ротация, кэш).
// 0 — только важные сообщения (ошибки, переходы алерта).
#define VERBOSE_LOGGING      1

// Короткие обёртки для verbose-логов.
#if VERBOSE_LOGGING
  #define VLOG(...)   Serial.printf(__VA_ARGS__)
  #define VLOGLN(s)   Serial.println(s)
#else
  #define VLOG(...)   ((void)0)
  #define VLOGLN(s)   ((void)0)
#endif

// --- Пороги алерта (гистерезис, см. logic::update_alert_state) ---
#define ALERT_CO2_ON         1500
#define ALERT_CO2_OFF        1300

// --- UI ---
#define UI_ALERT_TEXT        "VENTILATE"

// --- Average cache (Этап 13) ---
#define CACHE_VERSION        1
#define CACHE_PATH           "/cache/average_cache.bin"
#define CACHE_HISTORY_DAYS   30      // сколько дней истории берём для пересчёта
#define AVG_POINTS_1H        12
#define AVG_POINTS_24H       144
#define AVG_POINTS_7D        168
#define AVG_WINDOW_1H        12      // raw measurement за 1 час
#define AVG_WINDOW_24H       288     // raw за 24 часа
#define AVG_WINDOW_7D        2016    // raw за 7 дней

// --- Геометрия экрана (после setRotation — 250×122) ---
// Поворот панели. 1 = «обычная» альбомная ориентация, 3 = перевёрнутая на 180°.
// В собранном корпусе экран установлен ВВЕРХ НОГАМИ, поэтому 3 (картинка
// переворачивается, все координаты ниже остаются прежними — GFX сам
// трансформирует). Если соберёшь иначе — поставь 1.
#define EPD_ROTATION   3
#define SCREEN_W       250
#define SCREEN_H       122

// Поля (отступы от краёв) — специально с запасом, чтобы у физического
// края рамки экрана ничего не «срезалось» и смотреть было удобно.
#define PAD_L          26        // слева: место под подписи оси Y
#define PAD_R          12        // справа
#define PAD_T          20        // сверху: строка заголовка
#define PAD_B          16        // снизу: подписи оси X

// Область графика.
#define PLOT_X         PAD_L
#define PLOT_Y         PAD_T
#define PLOT_W         (SCREEN_W - PAD_L - PAD_R)   // 212
#define PLOT_H         (SCREEN_H - PAD_T - PAD_B)   // 86
#define PLOT_B         (PLOT_Y + PLOT_H)            // 106 — низ графика (baseline)

SensirionI2cScd4x scd4x;
GxEPD2_BW<EPD_DRIVER, EPD_DRIVER::HEIGHT> display(
    EPD_DRIVER(PIN_EPD_CS, PIN_EPD_DC, PIN_EPD_RST, PIN_EPD_BUSY)
);

// --- RTC memory ---
RTC_DATA_ATTR uint32_t rtc_magic = 0;
RTC_DATA_ATTR uint32_t wake_count = 0;
RTC_DATA_ATTR uint32_t total_uptime_before_sleep = 0;
RTC_DATA_ATTR int      current_screen = 0;
RTC_DATA_ATTR bool     last_valid = false;
RTC_DATA_ATTR uint16_t last_co2  = 0;
RTC_DATA_ATTR float    last_t    = 0.0f;
RTC_DATA_ATTR float    last_h    = 0.0f;
RTC_DATA_ATTR bool     alert_active = false;
RTC_DATA_ATTR uint32_t last_average_recalc_uptime = 0;
RTC_DATA_ATTR char     cached_file_path[64] = "";

// Что сейчас нарисовано на экране — чтобы по таймеру не обновлять зря.
RTC_DATA_ATTR uint32_t last_full_refresh_uptime = 0;
RTC_DATA_ATTR bool     last_shown_valid = false;
RTC_DATA_ATTR uint16_t last_shown_co2   = 0;
RTC_DATA_ATTR float    last_shown_t     = 0.0f;
RTC_DATA_ATTR float    last_shown_h     = 0.0f;
RTC_DATA_ATTR bool     last_shown_alert = false;
RTC_DATA_ATTR int      last_shown_screen = -1;   // какой экран сейчас на стекле
RTC_DATA_ATTR uint32_t tuning_mode = 0;          // 0=норм, 1=SETUP (без сна); смена долгим нажатием

// AverageCache: точное хранилище уже отрисовываемых точек.
// uint16 для CO2 (ppm), int16 для T*10 (десятые градуса),
// uint8 для % влажности. Размер ~1.6 КБ.
struct __attribute__((packed)) AverageCache {
    uint32_t version;
    uint8_t  has_data;
    uint8_t  reserved[3];
    uint16_t avg_co2_1h [AVG_POINTS_1H];
    uint16_t avg_co2_24h[AVG_POINTS_24H];
    uint16_t avg_co2_7d [AVG_POINTS_7D];
    int16_t  avg_temp_1h [AVG_POINTS_1H];
    int16_t  avg_temp_24h[AVG_POINTS_24H];
    int16_t  avg_temp_7d [AVG_POINTS_7D];
    uint8_t  avg_humidity_1h [AVG_POINTS_1H];
    uint8_t  avg_humidity_24h[AVG_POINTS_24H];
    uint8_t  avg_humidity_7d [AVG_POINTS_7D];
};
static AverageCache g_cache{};   // сессионная переменная (не RTC)

bool sensor_ok = false;
bool fs_ok     = false;

static const char* PARAM_NAMES[3]  = { "CO2", "Temperature", "Humidity" };
static const char* PERIOD_NAMES[3] = { "1 hour", "24 hours", "7 days" };

// ------------------------------------------------------------
// Хелперы (датчик, экран, sleep)
// ------------------------------------------------------------

static void print_scd_error(const char* fn, int16_t err) {
    char msg[64];
    errorToString(static_cast<uint16_t>(err), msg, sizeof(msg));
    Serial.printf("  %s: %d (%s)\n", fn, err, msg);
}

static void init_sensor() {
    Wire.begin(PIN_SDA, PIN_SCL);
    scd4x.begin(Wire, SCD41_I2C_ADDR_62);

    if (wake_count == 1) {
        scd4x.wakeUp();
        delay(30);
        int16_t serr = scd4x.stopPeriodicMeasurement();
        if (serr) {
            Serial.println("stopPeriodicMeasurement (ignored on first boot):");
            print_scd_error("stop", serr);
        }
        delay(500);
    }

    // После powerDown датчик просыпается не мгновенно, и первый wake_up он
    // не ACK'ает. Если сразу дёрнуть getSerialNumber — получим NACK
    // ("not responding") и пропустим замер → "No data" через раз. Поэтому
    // повторяем wakeUp + проверку связи, пока датчик не ответит.
    uint64_t sn = 0;
    int16_t err = 1;
    sensor_ok = false;
    for (int attempt = 1; attempt <= 5; attempt++) {
        scd4x.wakeUp();
        delay(50);
        err = scd4x.getSerialNumber(sn);
        if (!err) {
            sensor_ok = true;
            VLOG("SCD41 OK (attempt %d). SN: 0x%012llx\n",
                 attempt, (unsigned long long)sn);
            break;
        }
        delay(50);
    }
    if (!sensor_ok) {
        Serial.println("ERROR: SCD41 not responding after retries.");
        print_scd_error("getSerialNumber", err);
    }
}

static void init_display() {
    SPI.begin(PIN_EPD_SCK, -1, PIN_EPD_MOSI, PIN_EPD_CS);
    display.init(115200, /*initial=*/true, 10, false);
    display.setRotation(EPD_ROTATION);
    display.setTextColor(GxEPD_BLACK);
}

static void init_filesystem() {
    // false = не форматировать при ошибке монтирования. Если первый запуск
    // и раздел чистый — это вернёт false, тогда пробуем с format=true.
    if (!LittleFS.begin(false)) {
        Serial.println("LittleFS mount failed, formatting...");
        if (!LittleFS.begin(true)) {
            Serial.println("ERROR: LittleFS format failed too!");
            fs_ok = false;
            return;
        }
        Serial.println("LittleFS formatted and mounted");
    }
    fs_ok = true;

    if (!LittleFS.exists("/data")) {
        LittleFS.mkdir("/data");
        Serial.println("Created /data directory");
    }
    VLOG("LittleFS: %u / %u bytes used\n",
         (unsigned)LittleFS.usedBytes(),
         (unsigned)LittleFS.totalBytes());
}

// Сканируем /data/, возвращаем номера всех файлов measurements_NNN.bin
// (отсортированы по возрастанию).
static std::vector<int> list_data_file_numbers() {
    std::vector<int> result;
    File dir = LittleFS.open("/data");
    if (!dir || !dir.isDirectory()) return result;

    File entry = dir.openNextFile();
    while (entry) {
        if (!entry.isDirectory()) {
            // entry.name() в разных версиях LittleFS возвращает либо
            // "/data/measurements_001.bin", либо "measurements_001.bin".
            // extract_file_number обрабатывает оба варианта.
            int n = extract_file_number(std::string(entry.name()));
            if (n > 0) result.push_back(n);
        }
        entry.close();
        entry = dir.openNextFile();
    }
    dir.close();
    std::sort(result.begin(), result.end());
    return result;
}

// Возвращает путь к активному (последнему по номеру) файлу.
// Использует RTC-кэш cached_file_path. При первом обращении
// (или если кэш указывает на несуществующий файл) сканирует /data/.
static String get_current_file_path() {
    if (cached_file_path[0] != '\0' && LittleFS.exists(cached_file_path)) {
        return String(cached_file_path);
    }

    auto nums = list_data_file_numbers();
    int n = nums.empty() ? 1 : nums.back();
    std::string path = make_filename(n);
    std::strncpy(cached_file_path, path.c_str(), sizeof(cached_file_path) - 1);
    cached_file_path[sizeof(cached_file_path) - 1] = '\0';
    VLOG("Current file resolved: %s\n", cached_file_path);
    return String(cached_file_path);
}

// Создаём следующий файл по номеру и удаляем самый старый,
// если файлов теперь больше MAX_FILES. Обновляем RTC-кэш.
static void rotate_files() {
    auto nums = list_data_file_numbers();
    int current = nums.empty() ? 1 : nums.back();
    int next = next_file_number(current);

    std::string new_path = make_filename(next);
    File f = LittleFS.open(new_path.c_str(), "a", /*create=*/true);
    if (f) f.close();
    Serial.printf("Rotated to %s\n", new_path.c_str());

    std::strncpy(cached_file_path, new_path.c_str(), sizeof(cached_file_path) - 1);
    cached_file_path[sizeof(cached_file_path) - 1] = '\0';

    // Удаляем старейший, если общее число файлов перевалило за MAX_FILES.
    nums = list_data_file_numbers();
    int to_del = oldest_file_to_remove(nums, MAX_FILES);
    if (to_del > 0) {
        std::string p = make_filename(to_del);
        if (LittleFS.remove(p.c_str())) {
            Serial.printf("Deleted oldest: %s\n", p.c_str());
        } else {
            Serial.printf("Failed to delete: %s\n", p.c_str());
        }
    }
}
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
void loop() {
    // В нормальном режиме setup() уходит в deep sleep и сюда не возвращается.
    // Этот цикл крутится только в SETUP-режиме (без сна). Подстраховка:
    if (!tuning_mode) { go_to_sleep(); return; }

    // Опрос кнопки: короткое нажатие — листаем экраны, долгое (~10 c) — выходим
    // обратно в нормальный режим. Плюс периодический замер с обновлением.
    int btn = digitalRead(PIN_BUTTON);
    if (g_btn_prev == HIGH && btn == LOW) {        // фронт нажатия
        delay(30);                                 // антидребезг
        if (digitalRead(PIN_BUTTON) == LOW) {
            unsigned long t0 = millis();
            while (digitalRead(PIN_BUTTON) == LOW && millis() - t0 < LONG_PRESS_MS) delay(10);
            if (digitalRead(PIN_BUTTON) == LOW) {
                Serial.println("Long press -> returning to NORMAL mode");
                tuning_mode = 0;
                draw_mode_message("NORMAL MODE", "sleep enabled");
                while (digitalRead(PIN_BUTTON) == LOW) delay(10);
                delay(50);
                // Сразу в нормальный режим (сон). Следующее пробуждение
                // (таймер/кнопка) пойдёт обычным путём. Без перезагрузки.
                go_to_sleep();   // не возвращается
            }
            // Короткое нажатие: листаем экран по кругу.
            current_screen = cycle_screen(current_screen, N_SCREENS);
            Serial.printf("Button: screen -> %d\n", current_screen);
            draw_current_screen(current_screen, g_tune_valid,
                                g_tune_co2, g_tune_t, g_tune_h);
        }
    }
    g_btn_prev = btn;

    if (millis() - g_tuning_last_ms > 20000) {
        uint16_t prev = g_tune_co2;
        tuning_measure_and_store();
        // Перерисовываем главный только при заметном изменении CO2 —
        // чтобы e-paper не «моргал» полным обновлением каждые 20 сек.
        if (current_screen == SCREEN_MAIN &&
            abs((int)g_tune_co2 - (int)prev) >= 30)
            draw_current_screen(current_screen, g_tune_valid,
                                g_tune_co2, g_tune_t, g_tune_h);
        g_tuning_last_ms = millis();
    }
    delay(20);
}

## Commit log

2026-05-15 Initial project specification
    Add CLAUDE.md with full technical specification for ESP32-S3 battery-powered
    air quality monitor (CO2/temperature/humidity via SCD41, e-Paper display,
    3xAA battery, ~1.5-2.5 months autonomy).
    Includes 14-stage iterative implementation plan, hardware pinout, screen
    layout, data storage scheme, power budget, and configuration constants.
2026-05-15 Stage 1: Hello World + project skeleton
    - platformio.ini: two environments (esp32-s3-supermini, native)
    with lib_deps for SCD41, GxEPD2, Adafruit GFX/BusIO.
    - src/main.cpp: Serial banner + LED blink on GPIO 48 (RGB WS2812
    via neopixelWrite).
    - lib/logic/{logic.h,logic.cpp}: pure-logic library skeleton, to be
    filled per implementation stage.
    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
2026-05-15 Stage 2: SCD41 readout to Serial
    - Wire on GPIO 8/9, SCD41 at I2C address 0x62.
    - Single-shot measurement pattern (measureSingleShot → 5s delay →
    readMeasurement) — matches the future deep-sleep architecture.
    - On boot: stop any leftover periodic mode, read serial number to
    confirm I2C link; if missing, log diagnostic + retry in loop.
    - LED becomes a status indicator: green during measurement,
    yellow on sensor offline, off otherwise.
    - Helper print_scd_error() decodes Sensirion error codes via
    errorToString from SensirionCore.
    API note: Sensirion library 1.1.0 renamed the class to
    SensirionI2cScd4x (lowercase c) and changed getSerialNumber to a
    single uint64_t parameter — co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
    [main.cpp]
2026-05-15 Stage 3: e-Paper Hello
    - Initialise SPI on GPIO 12/11/10 (SCK/MOSI/CS), DC=13, RST=6, BUSY=7.
    - GxEPD2 with GxEPD2_213_B73 driver (SSD1680, most common Waveshare
    2.13" controller). If screen stays blank or shows garbage, try
    B72/BN/DEPG0213BN — both template type and constructor must change.
    - Full-window refresh draws "Hello, e-Paper!", "Stage 3 OK" and
    a border rectangle, then hibernates the controller — image stays
    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
2026-05-15 Stage 4: SCD41 + e-Paper combined
    - setup() initialises both sensor and display.
    - loop(): measure (5s) → log to Serial → repaint full screen → pad
    to a 30s cycle. LED green during measurement, dark otherwise.
    - draw_values() renders three lines (CO2/T/H) with a frame border;
    shows "No data" placeholder while waiting for first valid reading.
    - Refactored helpers init_sensor/init_display/take_measurement/
    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
2026-05-15 Stage 5: deep sleep + RTC memory
    - Cycle is now wake → measure → display → powerDown → sleep 5 min.
    - Three RTC_DATA_ATTR variables survive deep sleep: rtc_magic (with
    0xDEADBEEF magic guard against power-on garbage), wake_count, and
    total_uptime_before_sleep (accumulated awake-seconds).
    - First wake (wake_count == 1) draws a "Warming up sensor..." screen
    via partial refresh (fast, no flicker) while the 5-second single
    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
2026-05-15 Stage 6: buttons + screen navigation
    Pure logic (lib/logic):
    - cycle_param/cycle_period implement the 9-screen grid:
    screen = param_idx*3 + period_idx (CO2/T/H × 1h/24h/7d).
    Out-of-range input returns 0 to guard against RTC-memory garbage.
    Unit tests (test/test_logic):
    - 10 cases cover every transition in both directions, the
    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
2026-05-15 Stage 7: persist measurements to LittleFS
    - struct Measurement: packed, exactly 10 bytes (static_assert
    guards against accidental padding).
    - is_measurement_valid: CO2 (0,10000), temp_x10 (-400,500),
    humidity ≤ 100.
    - make_filename / extract_file_number / next_file_number for
    the /data/measurements_NNN.bin scheme. extract is lenient about
    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
2026-05-15 Stage 8: file rotation by size with MAX_FILES limit
    - oldest_file_to_remove(numbers, max_files): returns min element of
    the list when size exceeds max_files, else -1. Handles unsorted
    input and non-contiguous numbers (post-rotation history may have
    holes like 5..18).
    Tests: 6 new cases — empty list, under/at/over the limit, unsorted
    input, gappy ranges. 25 total cases, all green.
    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
2026-05-15 Stage 9: CO2 1h bar graph
    - downsample(input, target_size): simple bucket-averaging that
    handles empty input (returns zeroed output), non-positive target
    (returns empty), passthrough (target == input size), upscale
    (each output bucket gets the corresponding input), and the
    real 288→144 case used for 24h graphs.
    Tests: 6 new cases covering all the above. 31 total, all green.
    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
2026-05-15 Stage 13: average cache + dotted average line on graphs
    - calculate_window_average(history, real_window, target_size):
    walks `history` in real_window-sized chunks, averages position
    i across all chunks into target_size output buckets. Handles
    empty / sub-window history (returns zeros), zero/negative sizes
    (returns empty), and the real 288→144 case used for 24h graphs.
    Tests: 7 new cases — uniform history, position-progressive two
    windows, 4-to-2 manual case, the 288→144 24h shape, empty input,
    history shorter than one window, invalid size args.
    53 total, all green.
    Firmware:
    - AverageCache struct (packed, ~1.6 KB): 12+144+168 slots per
    parameter, wit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
    [main.cpp]
2026-05-15 Stage 14: polish + integration test
    - VERBOSE_LOGGING flag plus VLOG/VLOGLN macros: chatty logs
    (per-record writes, FS sizes, SN reads, cache load/save,
    rotation, current-file resolution) become no-ops when the
    flag is 0. Important lines (errors, alert transitions,
    wake cause, CO2/T/H per cycle) remain unconditional.
    - Cleaned up Stage 13's order-of-definition workaround:
    TARGET_POINTS now lives once near the top alongside the
    forward decl for load_recent_measurements; the duplicate
    TARGET_POINTS_FWD is gone.
    Tests:
    - New test_integration_synthetic_month synthesises 30 days ×
    288 = 8640 plausible measurements (day/night CO2 pattern,
    sinusoidal temperature, 45..6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
    [main.cpp]
2026-05-15 Add hardware bring-up runbook
    BRINGUP.md walks the AI assistant (and the user via the assistant)
    through verifying every stage on real hardware:
    - Pre-flight checklist before the first upload.
    - Common pio commands (upload / monitor / erase / BOOT+RESET).
    - Per-stage: commit hash, wiring, exact upload commands, expected
    Serial output, expected visual behaviour, diagnosis tree.
    - Stage 8 (rotation) and Stage 13 (averages) include accelerated
    test recipes (temporary MAX_FILE_SIZE / AVERAGE_RECALC_INTERVAL
    overrides) since the natural timing is days.
    - Table of all tunable #defines and when to touch them.
    - Short troubleshooting database for the most likely issues.
    CLAUDE.md gets a singl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
2026-06-09 Use GxEPD2_213_BN e-Paper driver
    The Waveshare 2.13 panel in this build is SSD1680/BN. With B73 the controller completes a full update but the glass stays blank; BN renders correctly.
    [main.cpp]
2026-06-09 Wake SCD41 reliably before each measurement
    After powerDown the sensor does not wake instantly and ignores the first wake_up, so getSerialNumber got a NACK every other cycle and the measurement was skipped (No data alternating). init_sensor now retries wakeUp + getSerialNumber until the sensor answers, and take_measurement retries the single-shot until a valid reading.
    [main.cpp]
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2026-06-10 Add power saving: 15-min interval, light sleep on measure, lazy screen refresh
    Measurement interval 5->15 min. ESP light-sleeps (~1-2 mA vs ~40 mA) during the 5s SCD41 single-shot wait. Screen redraws only on button press, on a significant value change, on alert change, or hourly (e-Paper holds the image for free otherwise). go_to_sleep clears stale wakeup sources and releases any GPIO hold before re-arming ext1, so the light sleep no longer breaks button wakeup.
    [main.cpp]
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2026-06-14 Add enclosure design: BOX.md spec + parametric OpenSCAD model
    [case.scad]
2026-06-14 Export printable STLs (shell + lid); fix corner screw ears
    [case.scad, case_lid.stl, case_shell.stl]
2026-06-14 Rework enclosure: slide-in seats, sliding lid with detent, dual vents, single STL
    [case.scad, case.stl, case_lid.stl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]
2026-06-14 Enclosure v2: snap-post board mounts, vented SCD41 chamber, snap-fit lid
    [case.scad, case.stl]
2026-06-14 Enclosure lid: battery-cover style (bottom lip + top snap tabs); tune board clamps
    [case.scad, case.stl]
2026-06-14 Two-level layout: removable shelf (battery floor / electronics cover), battery holder ribs
    [case.scad, case.stl]
2026-06-14 Add button mounts + SCD41 cable pass-through; fix board posts protruding outside box
    [case.scad, case.stl]
2026-06-14 Fix shelf battery ribs (were overhanging); split into 3 STLs; remove non-working button frame
    [case.scad, case.stl, case_lid.stl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]
2026-06-14 Buttons: 12x12 tactile stacked vertically with working pocket+lip mount (Ø7 actuator); compact +5mm height
    [case.scad, case_lid.stl, case_shelf.stl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]
2026-06-14 Redesign v5: horizontal, single button, SCD sensor-in-port seat, switch access, component+Dupont ghosts, embossed label, single 3-object STL
    [case.scad, case.stl, case_lid.stl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]
2026-06-18 Apply measured component dims (battery 58x48x17, SCD 21.6x13.4, button, Dupont 17mm); separate switch slot 7x3; save DIMENSIONS.md
    [case.scad, case.stl]
2026-06-18 e-Paper window offset (5/3.25), USB-C 3mm, e-paper 8-pin header in ghosts; finalize measured dims
    [case.scad, case.stl]
2026-06-18 Tolerance pass: generous clearances everywhere (fit 0.5, chamber 27, window/USB/button/port margins); firmware 1-button nav to TODO
    [case.scad, case.stl]
2026-06-18 Style redesign v6: rounded body (R8), centered framed screen w/ rounded window, sensor grille, side button, symmetric clean face
    [case.scad, case.stl]
2026-06-18 Fix v6 anomalies: grille/sensor under screen (drop overlapping round port), label position, clip internal ledges/ribs to rounded shell
    [case.scad, case.stl]
2026-06-18 v6 iter: button to front-right + label left (balanced), grille clears screen, fix label (raised outside, readable), ESP/USB left, switch body space, R10 + front chamfer
    [case.scad, case.stl]
2026-06-18 v6 careful pass: working lid snap (tabs->wall windows)+flip in print; simple glue ledges for all parts+button; SCD ledge web (fix non-manifold); grille lower/taller/9-slot; verified by render
    [case.scad, case.stl]
2026-06-18 Lid: tabs flush in windows (no protrusion), remove finger notch; grille lowered (clear of screen); re-add CO2 label mirror
    [case.scad, case.stl]
2026-06-18 Box v7: remove SCD chamber (blocked grille) -> corner supports; hidden lid snap (no wall holes); free e-paper cable; grow bezel
    [case.scad, case.stl]
2026-06-26 UI redesign: CO2-only, single button, 4 screens (main + 1h/24h/7d)
    - One button (GPIO5) cycles 4 screens; timer wake always returns to main
    - Minimalist layout with margins from edges; large CO2 value on main
    - Fix graphs: window sized from real MEASUREMENT_INTERVAL and data
    stretched across full width (no more ~40% empty left / inflated 24h-7d)
    - Fix SCD41 temperature: set single-shot temperature offset each cycle
    (factory 4C default for continuous mode made readings ~4-6C too low)
    - logic: add cycle_screen() + unit tests; all native tests green
    [main.cpp]
2026-06-26 Flip display 180 (EPD_ROTATION=3) for upside-down case mount
    [main.cpp]
2026-08-19 UI rework: pixel-art screens, 3-screen cycle, on-the-fly SETUP mode
    - main screen redrawn from pixel-art templates (main_screen.h, mascot.h),
    graph shells for 24h/7d (graph24_shell.h, graph7d_shell.h)
    - drop the 1h graph: at a 15 min interval it only had 4 points -> 3 screens
    - SETUP mode toggled by a ~10 s long press (RTC flag): no sleep, CPU 240 MHz,
    USB-CDC stays up so the device can be reflashed without catching a wake window
    - synthetic 7-day seeding behind SEED_SYNTHETIC for graph testing
    - software humidity offset hook (HUMIDITY_OFFSET), still 0 here
    [main.cpp]
2026-08-19 Calibrate humidity: +9.5 %RH offset (temperature needs none)
    10 paired readings over a day (36-54 %RH, 22.9-26.8 C) against a Xiaomi
    hygrometer (SHT3x class, +-3 %RH) and a noname Chinese one:
    Xiaomi - ours: 10,11,10,9,10,10,10,8,9,8 -> mean +9.5, median +10
    noname - ours: 1,2,1,0,3,1,0,0,0,0 -> mean +0.8
    Regression ours->Xiaomi is y = 0.87x + 14.9, i.e. an almost pure shift, so a
    constant +9.5 keeps the error within +-1.5 %RH across the range; gain+offset
    would be overkill. Trusting Xiaomi over the 2-vs-1 majority: RH is a secondary
    channel on the SCD41 (+-6 %RH spec) while Xiaomi is +-3 %, the noname is itself
    off by +0.5 C on temperature, and 37 % at 25 C in July is heating-s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
    [main.cpp]
2026-08-19 Add lid renders, screen design sources and print-ready STLs
    - box/_lid.* : lid geometry and render passes
    - "Дизайн экрана"/ : pixel-art sources the screen templates were traced from
    - "Печать"/ : STLs actually sent to print (whole case + 3 parts)
    - gitignore the print service's .glb/.zip exports: ~7 MB duplicates of the STLs
    [1.stl, 2.stl, 3.stl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]
